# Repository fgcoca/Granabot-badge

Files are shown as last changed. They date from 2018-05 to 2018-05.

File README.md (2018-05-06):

# **Documentación del badge Granabot** 
Se trata de una PCB diseñada en base al logo de Granabot como un kit de soldadura SMD y se basa en un micro controlador ATTiny85 y unos cuantos LEDs con control inteligente tipo WS2812B.

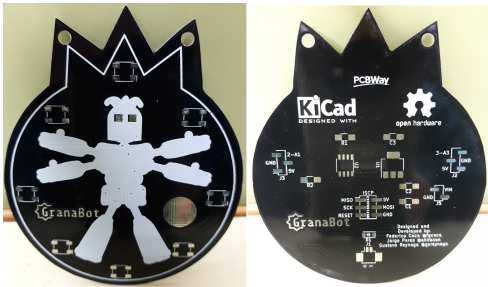
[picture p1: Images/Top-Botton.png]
GrB


 [1]: https://github.com/fgcoca/Granabot-badge/blob/master/Images/Top-Botton.png

# **Contenidos del repositorio**
1. Diseños originales de Gustavo Reynaga de la PCB realizados con [KICad](http://kicad-pcb.org/)

    * [Granabot badge original](https://github.com/fgcoca/Granabot-badge/tree/master/Granabot-Badge-Original)
    * [Imágenes para el diseño](https://github.com/fgcoca/Granabot-badge/tree/master/Granabot-Badge-Original/Design/images)
    * [Diseño para el patrocinio de PCBWay](https://github.com/fgcoca/Granabot-badge/tree/master/Granabot-Badge-Original/Hardware/PCBWay)
    * [Diseño para patrocinio de OSH Park](https://github.com/fgcoca/Granabot-badge/tree/master/Granabot-Badge-Original/Hardware/OSHPark)
2. Debido a dos pequeños errores de encapsulado en el diseño original de Gustavo se hace necesaria la revisión de este para dotar al Attiny85 y al diodo MBRA140 de footprint correctos. La citada revisión y adaptación la Realiza francisco López.

    * [Granabot badge revisado](https://github.com/fgcoca/Granabot-badge/tree/master/Granabot-Badge-revisado)
    * [Diseño para el patrocinio de PCBWay](https://github.com/fgcoca/Granabot-badge/tree/master/Granabot-Badge-revisado/Hardware/PCBWay)
    * [Diseño para patrocinio de OSH Park](https://github.com/fgcoca/Granabot-badge/tree/master/Granabot-Badge-revisado/Hardware/OSHPark)
   
3. Firmware de prueba cargado en los badges que se entregan que sirve para probar el funcionamiento simplemente con alimentarlo. Se trata de un archivo .ino listo para cargarr en el ATTiny85 via ICSP. En el [manual de uso](https://github.com/fgcoca/Granabot-badge/blob/master/Kit/Programacion/Manual.pdf) se explican todos los detalles para trabajar con el badge.
    * [Firmware](https://github.com/fgcoca/Granabot-badge/tree/master/Firmware/badge_granabot)

4. El Kit. Al badge Granabot se le da formato de kit para su entrega estando este formado por la PCB, los componentes necesarios para montarlo, un manual de montaje impreso y una fe de erratas. Todo ello introducido en una cajita adornada con [pegatinas](https://github.com/fgcoca/Granabot-badge/tree/master/Pegatinas-Caja) de Granabot y de los patrocinadores. En las imágenes se ve el aspecto final del kit listo para su entrega de una caja individual y de un conjunto de cajas preparadas para su entrega el día de la celebración del evento [Granabot](https://sites.google.com/site/granabot18/)

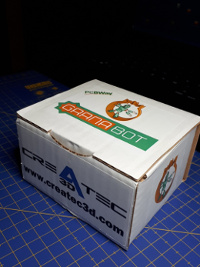
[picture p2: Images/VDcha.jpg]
Vista desde la derecha
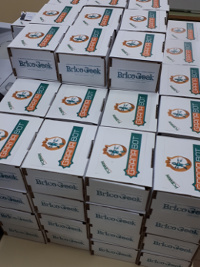
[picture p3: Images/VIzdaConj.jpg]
Conjunto visto desde la izquierda
 

 [10]: https://github.com/fgcoca/Granabot-badge/blob/master/Images/VDcha.jpg
 [11]: https://github.com/fgcoca/Granabot-badge/blob/master/Images/VIzdaConj.jpg

En la imagen vemos a Juan Robles de [Createc](https://createc3d.com/) (uno de nuestros patrocinadores) con el badge recien entregado.

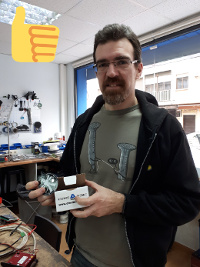
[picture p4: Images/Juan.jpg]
Juan Robles


 [12]: https://github.com/fgcoca/Granabot-badge/blob/master/Images/Juan.jpg

5. Información del kit Granabot

    * [Listas de materiales](https://github.com/fgcoca/Granabot-badge/tree/master/Kit/BOM)
      * [Formato .odt](https://github.com/fgcoca/Granabot-badge/blob/master/Kit/BOM/BOM-con-links-compras.ods)
      * [Formato .pdf](https://github.com/fgcoca/Granabot-badge/blob/master/Kit/BOM/BOM-con-links-compras.pdf)
      * [Formato .png](https://github.com/fgcoca/Granabot-badge/blob/master/Kit/BOM/BOM.png)      
    * [Erratas en la primera edición del kit](https://github.com/fgcoca/Granabot-badge/tree/master/Kit/Erratas)
      * [Formato .odt](https://github.com/fgcoca/Granabot-badge/blob/master/Kit/Erratas/Erratas.odt)
      * [Formato .pdf](https://github.com/fgcoca/Granabot-badge/blob/master/Kit/Erratas/Erratas.pdf)      
    * [Manuales de montaje](https://github.com/fgcoca/Granabot-badge/tree/master/Kit/Montaje)
      * [Formato comprimido .7z](https://github.com/fgcoca/Granabot-badge/blob/master/Kit/Montaje/Manual-montaje.7z)
      * [Formato .pdf](https://github.com/fgcoca/Granabot-badge/blob/master/Kit/Montaje/Manual-montaje.pdf)
      * [Formato .png](https://github.com/fgcoca/Granabot-badge/blob/master/Kit/Montaje/Manual-montaje.png)      
    * [Manuales de configuraciones y uso de librerias para programar el kit](https://github.com/fgcoca/Granabot-badge/tree/master/Kit/Programacion)
      * [Formato .odt](https://github.com/fgcoca/Granabot-badge/blob/master/Kit/Programacion/Manual.odt)
      * [Formato .pdf](https://github.com/fgcoca/Granabot-badge/blob/master/Kit/Programacion/Manual.pdf)
      * [Video de funcionamiento](https://github.com/fgcoca/Granabot-badge/blob/master/Kit/Programacion/video/Test-badge-Granabot.mp4)       
    * [Programando físicamente el kit](https://github.com/fgcoca/Granabot-badge/tree/master/Kit/Programando)
      * [Formato .odt](https://github.com/fgcoca/Granabot-badge/blob/master/Kit/Programando/Programando.odt)
      * [Formato .pdf](https://github.com/fgcoca/Granabot-badge/blob/master/Kit/Programando/Programando.pdf)        
    * [Pinza de sujeción diseñada en 3D](https://github.com/fgcoca/Granabot-badge/tree/master/Kit/Programando/Design)
      * [Diseño en FreeCAD](https://github.com/fgcoca/Granabot-badge/blob/master/Kit/Programando/Design/Pinzas-Centrador.FCStd)
      * [Archivo stl de la pinza](https://github.com/fgcoca/Granabot-badge/blob/master/Kit/Programando/Design/Pinza.stl)  
      * [Archivo stl de la pieza usada para posicionar el chip](https://github.com/fgcoca/Granabot-badge/blob/master/Kit/Programando/Design/Centrador.stl)

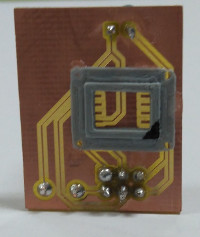
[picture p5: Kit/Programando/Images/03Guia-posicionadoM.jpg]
Guía de posicionado
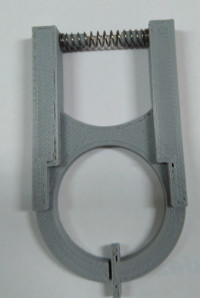
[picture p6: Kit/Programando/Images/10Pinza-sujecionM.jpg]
Pinza de sujeción con el muelle montado
 

 [20]: https://github.com/fgcoca/Granabot-badge/blob/master/Kit/Programando/Images/03Guia-posicionadoM.jpg
 [21]: https://github.com/fgcoca/Granabot-badge/blob/master/Kit/Programando/Images/10Pinza-sujecionM.jpg

# **Enlaces**

[Web de Granabot 2018](https://sites.google.com/site/granabot18/)

# **Autores**
Gustavo Reynaga https://github.com/hulkco @gsreynaga 

Jorge Pérez https://github.com/akirasan @akirasan

José Antonio Vacas https://github.com/javacasm @javacasm

Federico Coca Caba https://github.com/fgcoca @fgcoca

Francisco López Castro @flopcas 

# **Licencia**
License

 [88]: https://github.com/fgcoca/3D-Design_Robots_Other/blob/master/Lapicero/Licencia/licencia.png
[Enlace al texto de la licencia](https://github.com/fgcoca/Granabot-badge/blob/master/LICENSE)

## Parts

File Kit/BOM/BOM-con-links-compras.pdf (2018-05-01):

BOM

## Granabot badge

Quantity | Reference | Value | Description | Supplier
1 | R1 | 1k | 1206 SMD resistor | Link (https://es.aliexpress.com/item/100pcs-lot-SMD-Chip-Resistor-1206-1K-1K-ohm-5-Free-shippng/32382933718.html)
1 | R2 | 1M | 1206 SMD resistor | Link (https://es.aliexpress.com/item/100pcs-lot-SMD-Chip-Resistor-1206-1M-1M-ohm-5-Free-shippng/32385434931.html)
1 | C1 | 4.7uF | 1206 SMD capacitor | Link (https://es.aliexpress.com/item/Free-shipping-1206-SMD-capacitor-4-7UF-25V-475ZM-100PCS/32373664747.html)
1 | C2 | 100nF | 1206 SMD capacitor | Link (https://es.aliexpress.com/item/Free-shipping-1206-SMD-capacitor-100nf-50V-104K-100PCS/32372347475.html)
1 | C3 | 22nF | 1206 SMD capacitor | Link (https://es.aliexpress.com/item/Free-shipping-1206-SMD-capacitor-220nf-50V-224M-100PCS/32373616228.html)
0 | CAP1 | CAPSENSE_CIRCLE | On PCB | None
1 | D1 | MBRA140 | Schottky diode | Link (https://es.aliexpress.com/item/20-unids-MBRA140-MBRA140T3G-DO-214AC/32845565830.html)
1 | D2 | Power | 1206 SMD LED Blue | Link (https://es.aliexpress.com/store/product/Smd-leds-led-smd-blu-ray-1206-languang-bright-double/430356_1288303428.html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)
8 | LED1 to LED8 | WS2812B | Intelligent control LED | Link (https://es.aliexpress.com/item/10-1000pcs-WS2812B-4pins-5050-SMD-Black-White-version-WS2812-Individually-Addressable-Digital-RGB-LED-Chip/32453497583.html)
1 | U1 | LM340MP-5.0/NOPB | Fixed Voltage Regulator | Link (https://es.aliexpress.com/item/LM340MP5-0-LM340-LM340MP-LM340MP-5-0-SOT223/32837352624.html)
1 | U2 | ATTINY85-20SU | Atmel 8-bit AVR Microcontroller | Link (https://es.aliexpress.com/item/FREE-SHIPPING-5piece-ATTINY85-20SU-SOP8-ATTINY85-20-SOP-ATTINY85-SMD-85-20SU/32771436223.html)
1 | J1 | CONN_01X02 | 1.25mm – Connector JST SMD Horizontal | Link (https://es.aliexpress.com/item/100-Set-1-25mm-Pitch-Connector-Mini-JST-Horizontal-Straight-Pin-2-3-4-5-6/32787329436.html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)
2 | J2, J3 | CONN_01X03 | 2.54mm - 1x40 Pins SMD Male | Link (https://es.aliexpress.com/item/200PCS-2-0mm-Pin-Headerr-SMT-1X40P-Single-Row-Single-Plastic-High-Quality-Gold-Plated/32795058148.html)
1 | J4 | CONN_02X03 | 2.54mm - 2x40 Pins SMD Male | Link (https://es.aliexpress.com/item/20pcs-lot-2x40-pins-Double-Row-2-54-mm-Pitch-SMD-Needle-Male-Pin-Header/1691091075.html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)
1 | J5 | CONN_01X02 | 2.54mm - 1x40 Pins SMD Male | Link (https://es.aliexpress.com/item/200PCS-2-0mm-Pin-Headerr-SMT-1X40P-Single-Row-Single-Plastic-High-Quality-Gold-Plated/32795058148.html)

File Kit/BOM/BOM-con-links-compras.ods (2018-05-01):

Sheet: BOM
Granabot badge
Quantity | Reference | Value | Description | Supplier
1 | R1 | 1k | 1206 SMD resistor | Link (https://es.aliexpress.com/item/100pcs-lot-SMD-Chip-Resistor-1206-1K-1K-ohm-5-Free-shippng/32382933718.html)
1 | R2 | 1M | 1206 SMD resistor | Link (https://es.aliexpress.com/item/100pcs-lot-SMD-Chip-Resistor-1206-1M-1M-ohm-5-Free-shippng/32385434931.html)
1 | C1 | 4.7uF | 1206 SMD capacitor | Link (https://es.aliexpress.com/item/Free-shipping-1206-SMD-capacitor-4-7UF-25V-475ZM-100PCS/32373664747.html)
1 | C2 | 100nF | 1206 SMD capacitor | Link (https://es.aliexpress.com/item/Free-shipping-1206-SMD-capacitor-100nf-50V-104K-100PCS/32372347475.html)
1 | C3 | 22nF | 1206 SMD capacitor | Link (https://es.aliexpress.com/item/Free-shipping-1206-SMD-capacitor-220nf-50V-224M-100PCS/32373616228.html)
0 | CAP1 | CAPSENSE_CIRCLE | On PCB | None
1 | D1 | MBRA140 | Schottky diode | Link (https://es.aliexpress.com/item/20-unids-MBRA140-MBRA140T3G-DO-214AC/32845565830.html)
1 | D2 | Power | 1206 SMD LED Blue | Link (https://es.aliexpress.com/store/product/Smd-leds-led-smd-blu-ray-1206-languang-bright-double/430356_1288303428.html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)
8 | LED1 to LED8 | WS2812B | Intelligent control LED | Link (https://es.aliexpress.com/item/10-1000pcs-WS2812B-4pins-5050-SMD-Black-White-version-WS2812-Individually-Addressable-Digital-RGB-LED-Chip/32453497583.html)
1 | U1 | LM340MP-5.0/NOPB | Fixed Voltage Regulator | Link (https://es.aliexpress.com/item/LM340MP5-0-LM340-LM340MP-LM340MP-5-0-SOT223/32837352624.html)
1 | U2 | ATTINY85-20SU | Atmel 8-bit AVR Microcontroller | Link (https://es.aliexpress.com/item/FREE-SHIPPING-5piece-ATTINY85-20SU-SOP8-ATTINY85-20-SOP-ATTINY85-SMD-85-20SU/32771436223.html)
1 | J1 | CONN_01X02 | 1.25mm – Connector JST SMD Horizontal | Link (https://es.aliexpress.com/item/100-Set-1-25mm-Pitch-Connector-Mini-JST-Horizontal-Straight-Pin-2-3-4-5-6/32787329436.html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)
2 | J2, J3 | CONN_01X03 | 2.54mm - 1x40 Pins SMD Male | Link (https://es.aliexpress.com/item/200PCS-2-0mm-Pin-Headerr-SMT-1X40P-Single-Row-Single-Plastic-High-Quality-Gold-Plated/32795058148.html)
1 | J4 | CONN_02X03 | 2.54mm - 2x40 Pins SMD Male | Link (https://es.aliexpress.com/item/20pcs-lot-2x40-pins-Double-Row-2-54-mm-Pitch-SMD-Needle-Male-Pin-Header/1691091075.html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)
1 | J5 | CONN_01X02 | 2.54mm - 1x40 Pins SMD Male | Link (https://es.aliexpress.com/item/200PCS-2-0mm-Pin-Headerr-SMT-1X40P-Single-Row-Single-Plastic-High-Quality-Gold-Plated/32795058148.html)

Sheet: 001
Reference | Value | Footprint | Datasheet | Description | MF_Name | MF_PN | S1_Name | S1_PN
LED1 | WS2812B | OSHwi:WS2812B | http://www.adafruit.com/datasheets/WS2812B.pdf | LED RGB WS2812B W/DVR 4SMD | Adafruit | 1655 | Digikey | 1528-1104-ND
LED2 | WS2812B | OSHwi:WS2812B | http://www.adafruit.com/datasheets/WS2812B.pdf | LED RGB WS2812B W/DVR 4SMD | Adafruit | 1655 | Digikey | 1528-1104-ND
LED3 | WS2812B | OSHwi:WS2812B | http://www.adafruit.com/datasheets/WS2812B.pdf | LED RGB WS2812B W/DVR 4SMD | Adafruit | 1655 | Digikey | 1528-1104-ND
LED4 | WS2812B | OSHwi:WS2812B | http://www.adafruit.com/datasheets/WS2812B.pdf | LED RGB WS2812B W/DVR 4SMD | Adafruit | 1655 | Digikey | 1528-1104-ND
LED5 | WS2812B | OSHwi:WS2812B | http://www.adafruit.com/datasheets/WS2812B.pdf | LED RGB WS2812B W/DVR 4SMD | Adafruit | 1655 | Digikey | 1528-1104-ND
J1 | CONN_01X02 | Connectors_Molex:Molex_PicoBlade_53261-0271_02x1.25mm_Angled
C1 | 4.7uF | Capacitors_SMD:C_1206_HandSoldering
R1 | 1k | Resistors_SMD:R_1206_HandSoldering
D2 | ON | LEDs:LED_1206_HandSoldering
D1 | MBRA140 | OSHwi:D_SOD-123 | http://www.vishay.com/docs/94301/vs-mbra140trpbf.pdf | DIODE SCHOTTKY 40V 1A MBRA140 SMA | Vishay | VS-MBRA140TRPBF | Digikey | VS-MBRA140TRPBFCT-ND
C2 | 0.1uF | Capacitors_SMD:C_1206_HandSoldering
C3 | 22nF | Capacitors_SMD:C_1206_HandSoldering
LED6 | WS2812B | OSHwi:WS2812B | http://www.adafruit.com/datasheets/WS2812B.pdf | LED RGB WS2812B W/DVR 4SMD | Adafruit | 1655 | Digikey | 1528-1104-ND
U2 | ATTINY85-20SU | Housings_SOIC:SOIC-8_3.9x4.9mm_Pitch1.27mm
U1 | LM340MP-5.0/NOPB | TO_SOT_Packages_SMD:SOT-223-3Lead_TabPin2 | http://www.ti.com/lit/ds/symlink/lm340.pdf
J4 | CONN_02X03 | Pin_Headers:Pin_Header_Straight_2x03_Pitch2.54mm_SMD
R2 | 1M Ohms | Resistors_SMD:R_1206_HandSoldering
CAP1 | CAPSENSE_CIRCLE | Granabot:CAPSENSE-CIRCLE2-D10MM
J5 | CONN_01X02 | Pin_Headers:Pin_Header_Straight_1x02_Pitch2.54mm_SMD_Pin1Left
LED7 | WS2812B | OSHwi:WS2812B | http://www.adafruit.com/datasheets/WS2812B.pdf | LED RGB WS2812B W/DVR 4SMD | Adafruit | 1655 | Digikey | 1528-1104-ND
LED8 | WS2812B | OSHwi:WS2812B | http://www.adafruit.com/datasheets/WS2812B.pdf | LED RGB WS2812B W/DVR 4SMD | Adafruit | 1655 | Digikey | 1528-1104-ND
J2 | CONN_01X03 | Pin_Headers:Pin_Header_Straight_1x03_Pitch2.54mm_SMD_Pin1Left
J3 | CONN_01X03 | Pin_Headers:Pin_Header_Straight_1x03_Pitch2.54mm_SMD_Pin1Right

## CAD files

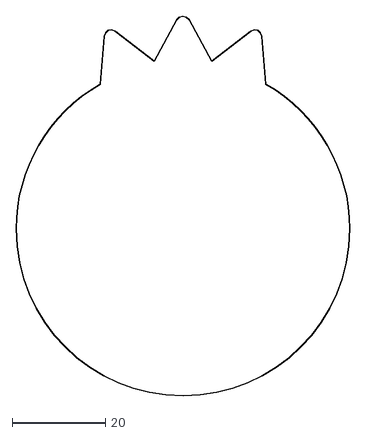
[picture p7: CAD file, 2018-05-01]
Granabot-Badge-Original/Design/images/DXF/contorno.dxf
71.5 x 81.3

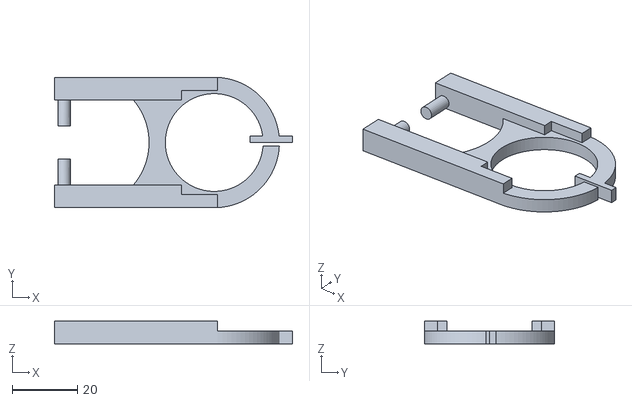
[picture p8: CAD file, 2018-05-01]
Kit/Programando/Design/Pinza.stl
73.0 x 40.0 x 7.00

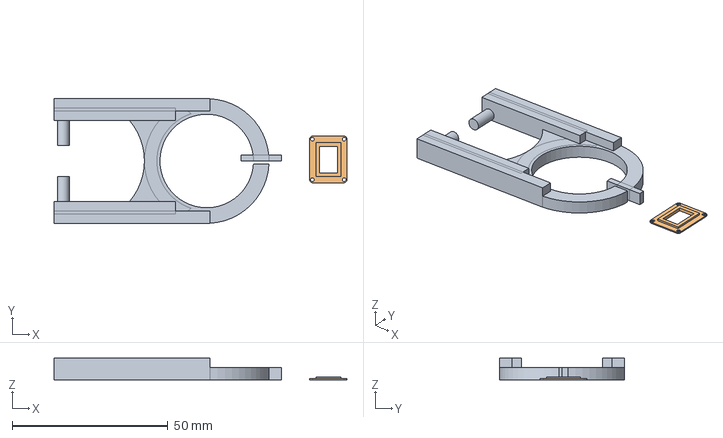
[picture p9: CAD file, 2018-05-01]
Kit/Programando/Design/Pinzas-Centrador.FCStd
94.0 x 40.0 x 7.00 mm
Clone of Pinza-final
Clone of Centrador

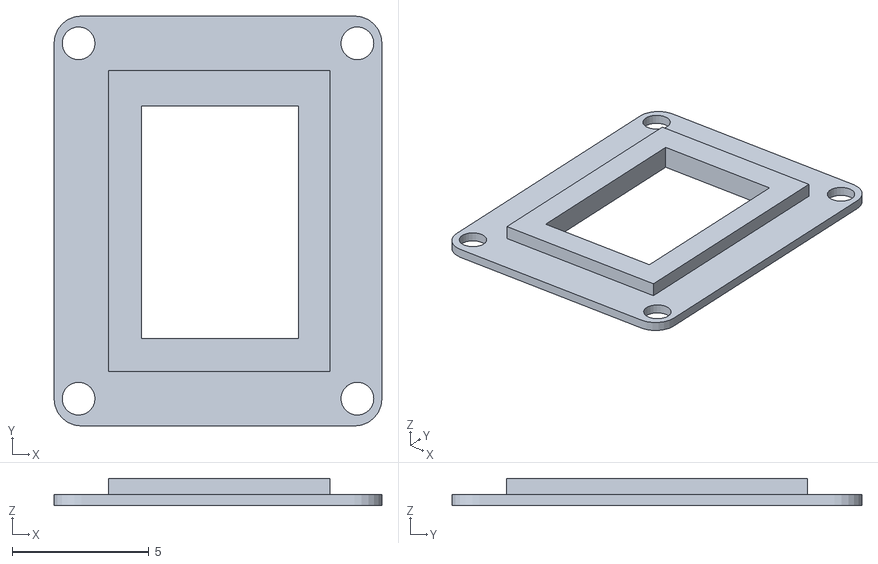
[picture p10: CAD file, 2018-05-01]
Kit/Programando/Design/Centrador.stl
12.0 x 15.0 x 1.00

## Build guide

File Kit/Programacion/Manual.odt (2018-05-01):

Granabot Badge

Guía de Programación

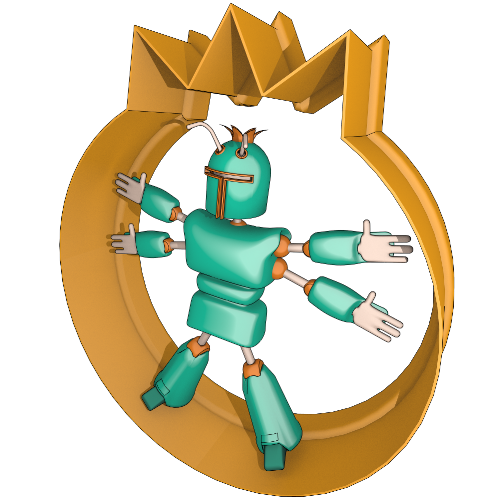
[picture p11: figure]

# Introducción

Los materiales que necesitaremos, además del propio badge, son una placa Arduino UNO o similar, que hará las funciones de programador, un cable ICSP, que deberemos confeccionar nosotros mismos, y un cable USB, para conectar la placa Arduino al ordenador. En cuanto a los programas y librerías necesarias, usaremos el propio IDE de Arduino, descargable desde www.arduino.cc, y las librerías CapacitiveSensor (https://github.com/PaulStoffregen/CapacitiveSensor), originalmente escrita por Paul Bagder y mantenida actualmente por Paul Sttofregen, y Adafruit_NeoPixel (https://github.com/adafruit/Adafruit_NeoPixel), de Adafruit. Ambas librerías las podemos instalar usando el gestor de librerías incluido en el IDE de Arduino.

# El cable ICSP

Nos va a permitir programar el ATTiny85 del badge a través del conector ICSP (In Circuit Serial Programming, programación serie en circuito). Consiste en un mazo o manguera de 6 cables. En uno de los extremos tiene un conector de 2x3 pines hembra, en nuestro caso construido a partir de dos tiras de 1x3 pines hembra unidas entre sí. En el otro extremo se encuentra otro conector similar al anterior pero en el que solo se usan 5 de los 6 pines. Al cable que en este extremo queda libre se le añade un pin macho.

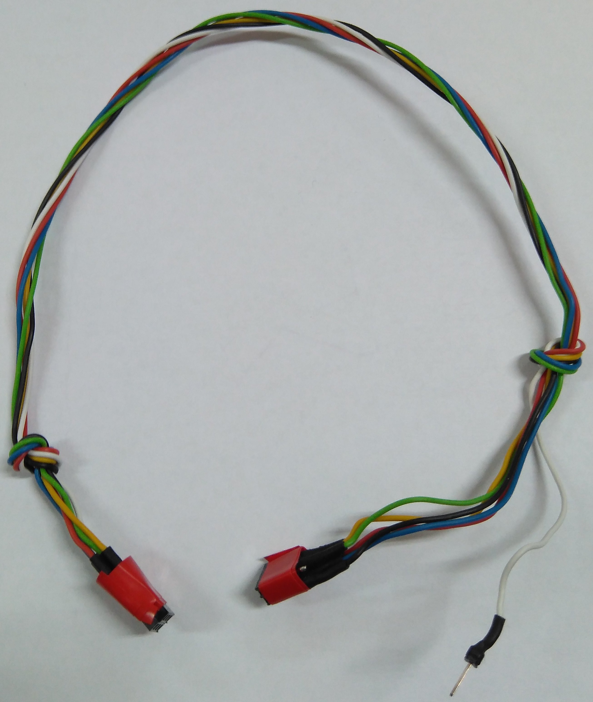
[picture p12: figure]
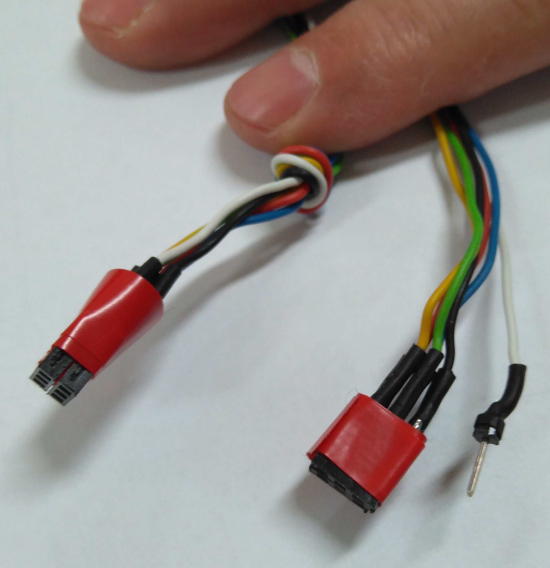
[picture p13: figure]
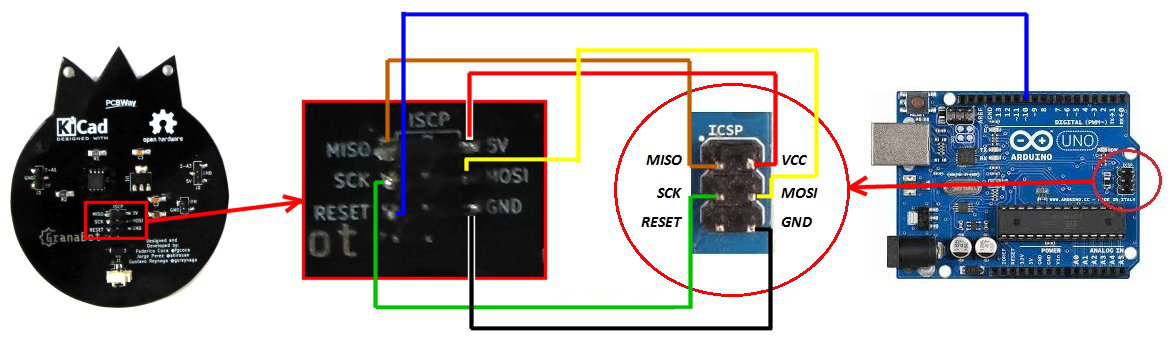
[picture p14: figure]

El conexionado entre el Badge y Arduino es el siguiente:

Una imagen real de este conexionado dará una mejor idea del mismo:

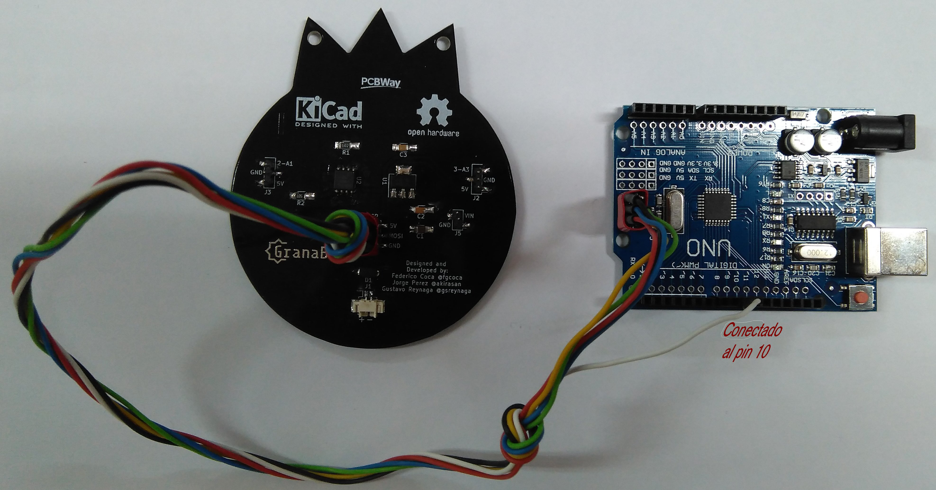
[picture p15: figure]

# Preparación de Arduino para usarlo como programador

Para poder programar el badge usando un Arduino (UNO en este caso) deberemos realizar un proceso que empieza por conectar el Arduino al ordenador y arrancar el IDE. Los ajustes de dicho IDE deberán ser los habituales, es decir, la placa seleccionada debe ser Arduino UNO y el puerto el adecuado:

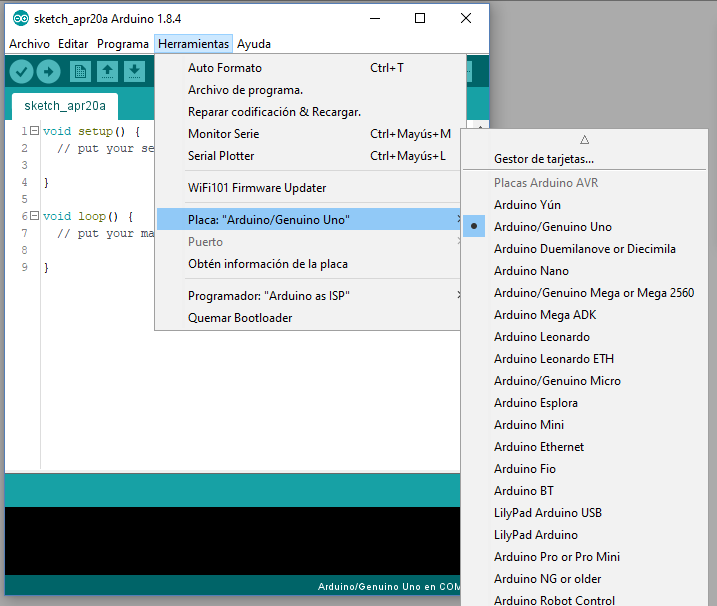
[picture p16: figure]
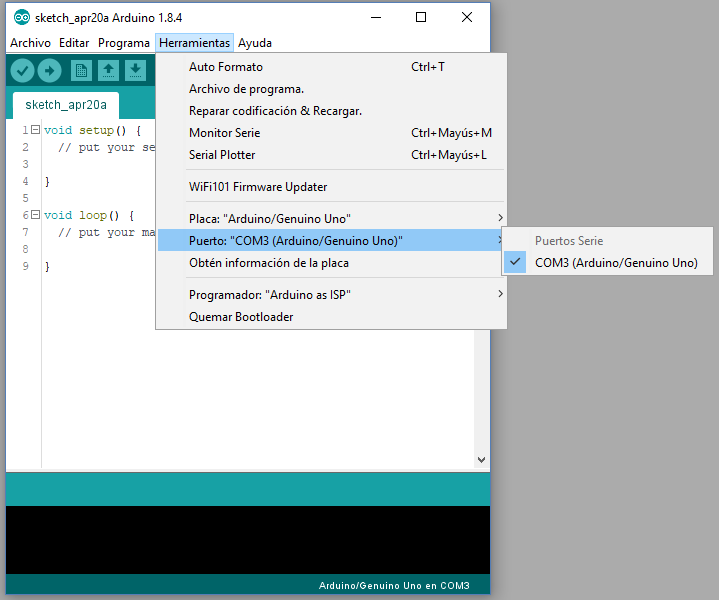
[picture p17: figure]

Seguidamente abriremos el ejemplo ArduinoISP:

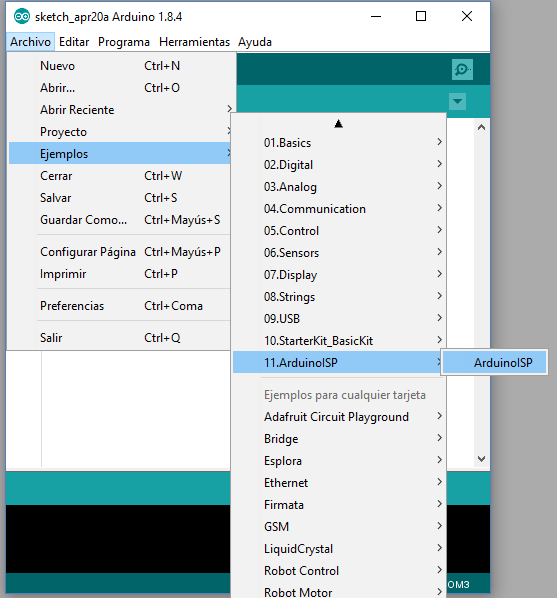
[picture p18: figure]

Cargaremos este sketch en Arduino UNO sin modificar nada del mismo. Tras esto nuestro Arduino se habrá convertido en un programador ICSP.

# Preparar el IDE para trabajar con el ATTiny85

El ATTiny85 no forma parte de las “placas” que el IDE de Arduino es capaz de programar. Sin embargo, gracias a David A. Mellis que ha desarrollado los cores necesarios, podemos hacer que el IDE reconozca nuestro ATTiny85 para poder programarlo como si de una placa Arduino más se tratara. Para lograr esto deberemos empezar por abrir el gestor de tarjetas:

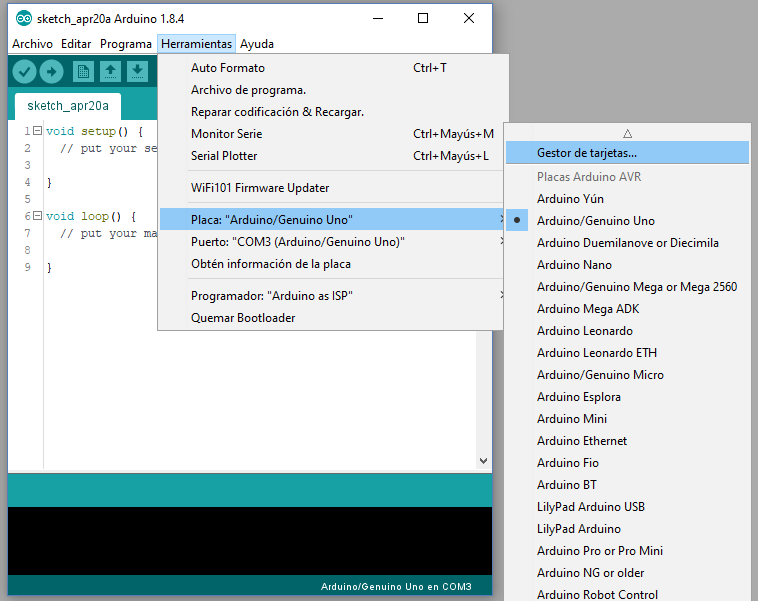
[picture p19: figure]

En dicho gestor buscaremos la tarjeta attiny:

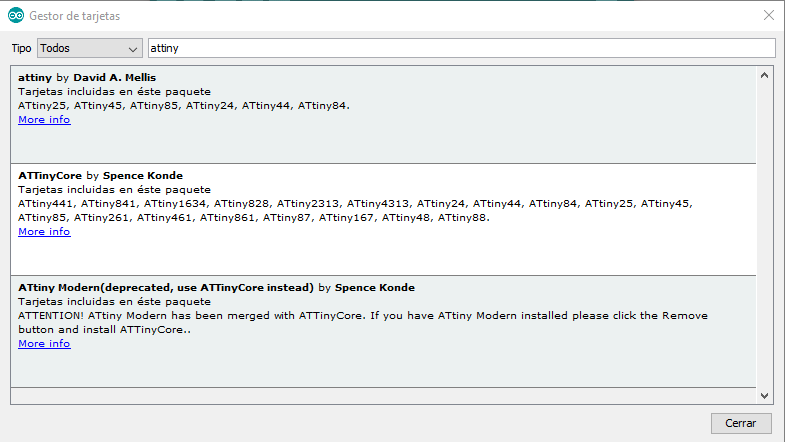
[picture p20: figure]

Seleccionaremos la tarjeta attiny by David A. Mellis y la instalaremos. A continuación seleccionaremos la tarjeta ATTiny85:

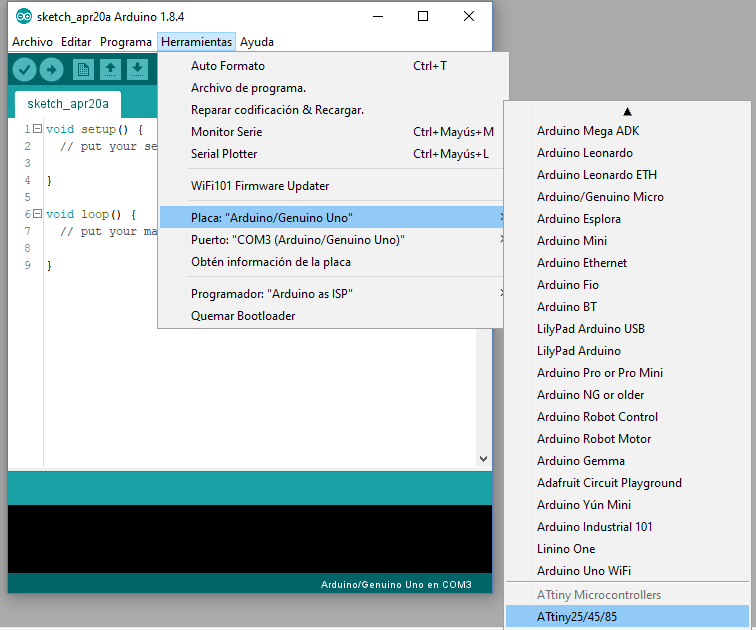
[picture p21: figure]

Tras hacer esto debemos seleccionar el ATTiny85:

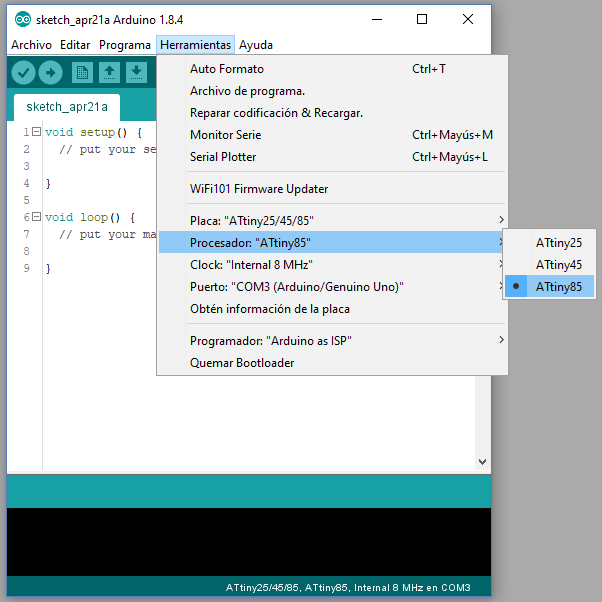
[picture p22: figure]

Por último deberemos indicarle al IDE que queremos usar el Ardunio UNO como programador del badge:

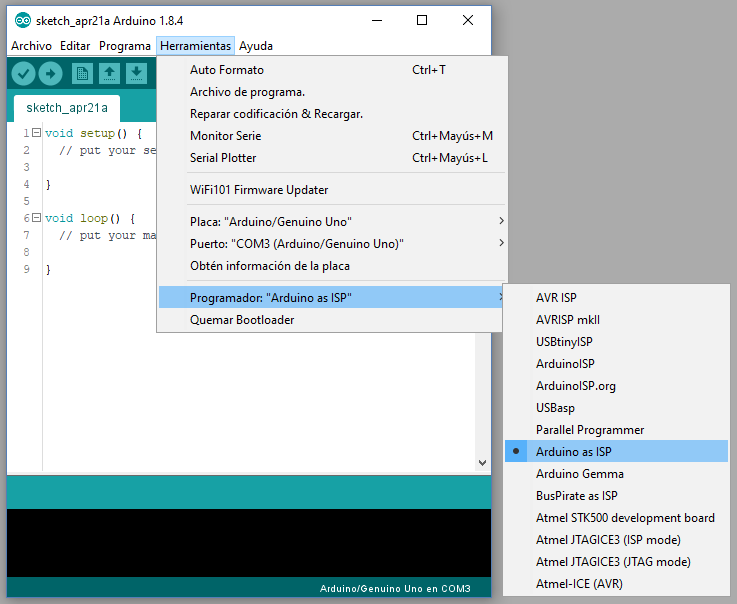
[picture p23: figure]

# Cambiar los fuses del ATTiny85

El ATTiny85 viene de fábrica con sus fuses programados de tal forma que está configurado para trabajar con el reloj interno a 1MHz. Con esta configuración por defecto el badge no puede usar la librería Adafruit Neopixel. Es por esto que en GranaBot suministramos el ATTiny85 del badge configurado para que use el reloj interno a 8MHz. Si se tiene necesidad de cambiar esto sólo hay que empezar por seleccionar la opción adecuada:

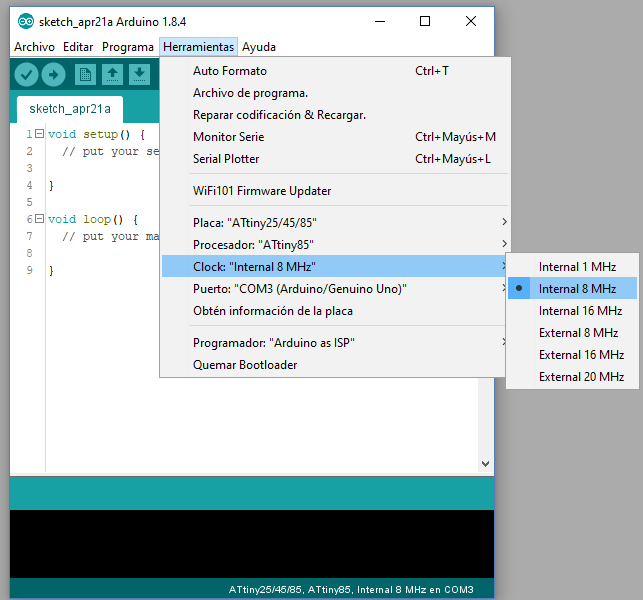
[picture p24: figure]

Y proceder a programar los fuses:

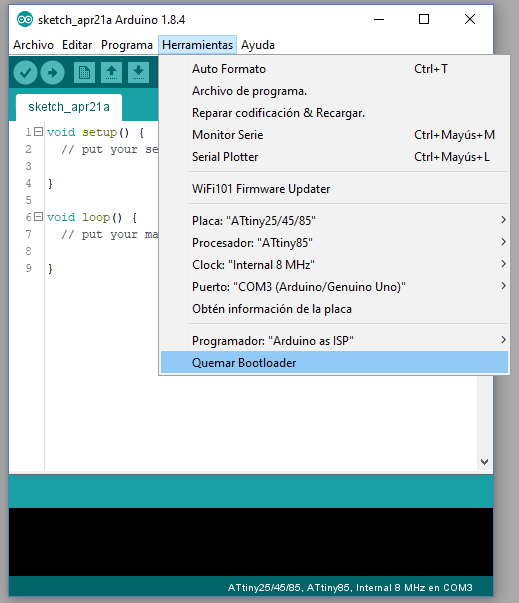
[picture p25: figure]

# Uso básico de la librería CapacitiveSensor

Es la librería que podemos usar para leer el sensor capacitivo incluido en el badge. Esta librería trabaja con un objeto de tipo CapacitiveSensor. Dicho objeto viene a ser una “digitalización” del sensor físico existente en el badge. Es decir, es una especie de representación digital abstracta, existente en el interior de Arduino, y que se corresponde con el sensor físico, real, disponible en la placa (Muy al estilo de Tron, una película estadounidense de 1982, del género ciencia ficción escrita y dirigida por Steven Lisberger).

El primer paso para trabajar con esta librería es incluirla como fichero de cabecera con la directiva #include :

#include <CapacitiveSensor.h>

Hecho esto deberemos continuar por crear una instancia de la clase CapacitiveSensor. Esta instancia es el objeto que representa al sensor físico del badge, tal como se ha comentado más arriba:

CapacitiveSensor mi_sensor = CapacitiveSensor (pin 1, pin2);

El objeto creado se llama en este caso mi_sensor y, debido al hardware del badge, el pin 1 deberá ser el pin PB0 y pin 2 el pin PB1.

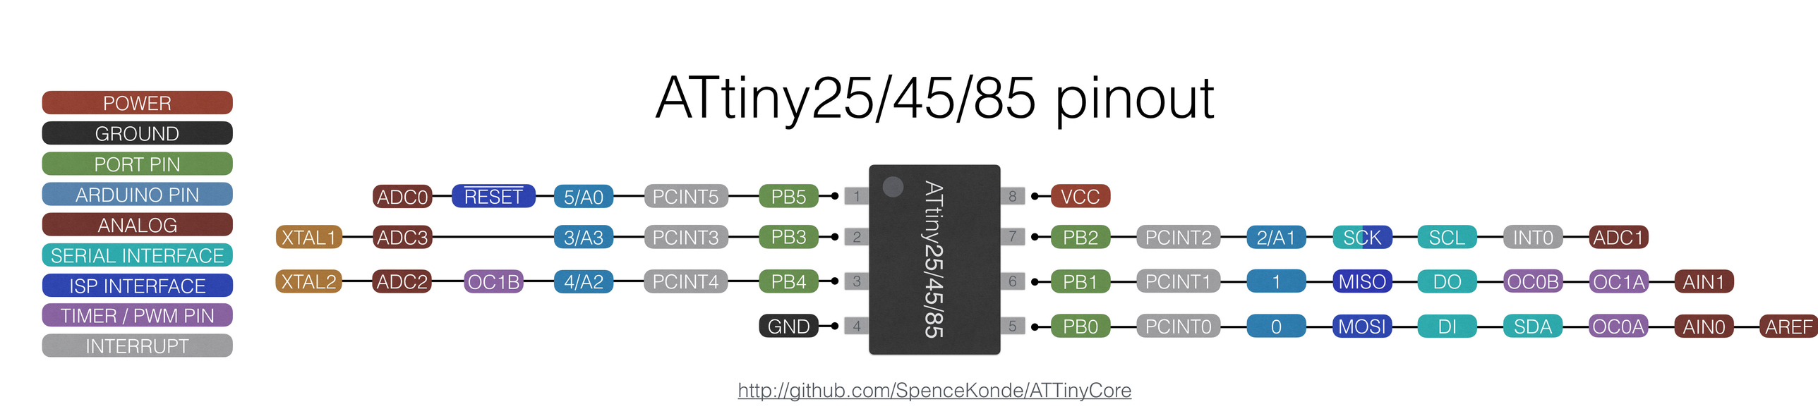
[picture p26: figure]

Para la lectura del sensor usaremos la función CapacitiveSensor(muestras). Esta función devuelve el valor de la capacidad que tiene el sensor (devolverá un valor bajo si no se está tocando el sensor) en unidades arbitrarias. El parámetro muestras específicamente cuantas muestras sucesivas se toman para determinar la capacidad del sensor durante la medida. El resultado devuelto será una media de todos los valores muestreados. Por tanto, para realizar una medida de la capacidad del sensor procederemos de la siguiente forma:

long medida_sensor = mi_sensor.CapacitiveSensor (10);

De esta forma en la variable medida_sensor se almacena el valor medio resultado de 10 medidas sucesivas de la capacidad del sensor. Si se toca el sensor este valor será más o menos elevado. Si no se toca será un valor bajo.

# Uso básico de la librería Adafruit_NeoPixel

Usaremos esta librería para el control de los LEDs RGB incluidos en el badge. Esta librería solo funciona con frecuencias de reloj del micro-controlador iguales o mayores de 8MHz. Como siempre, para poder usar las funciones disponibles en la librería deberemos empezar por incluir la misma en nuestro sketch:

#include <Adafruit_NeoPixel.h>

También, como en el caso descrito anteriormente, será necesario instanciar la clase Adafruit_NeoPixel para crear el objeto que representa a la “tira de LEDs” incluida en el badge:

Adafruit_NeoPixel mis_LEDs = Adafruit_NeoPixel (8, PB4, NEO_GRB + NEO_KHZ800);

El 8 se debe a que nuestro badge tiene 8 LEDs RGB. PB4 es el pin del ATTiny encargado de controlar los LEDs RGB. El resto… bueno, es lo que hay que poner en el caso que nos ocupa (ver https://learn.adafruit.com/adafruit-neopixel-uberguide/arduino-library-use o sketch de ejemplo strandtest.ino incluido al instalar la librería para más detalles).

Una vez creada nuestra “imagen virtual” de los LEDs del badge en el interior del ATTiny85 ya podemos empezar a controlarlos mediante las funciones que nos proporciona la librería. Habrá que empezar por ajustar el brillo máximo de los LEDs e inicializar el objeto creado. Normalmente esto se hace dentro del setup del sketch:

mis_LEDs.setBrightness(brillo);

mis_LEDs.begin();

El valor dado al brillo máximo tiene que ser de tipo byte, o sea, entre 0 y 255.

Para controlar el color de cada uno de los LEDs del badge usaremos la siguiente función:

mis_LEDs.setPixelColor(n, rojo, verde, azul);

Esta función ajusta el color del LED número n (en nuestro caso n es un número entero entre 0 y 7). Los colores, rojo, verde y azul, son de tipo byte. El efecto de esta función no se refleja inmediatamente en los LEDs. Para que ello ocurra deberemos mandar la nueva configuración de color de los LEDs a los mismos empleando la función siguiente:

mis_LEDs.show();

# Test de funcionamiento

En los enlaces siguientes podemos ver el video de funcionamiento del badge con el firmware grabado por defecto en el mismo.

Enlace al video en Youtube –> https://youtu.be/pwC2fTl5S1I

Enlace al video en Github –> https://github.com/fgcoca/Granabot-badge/blob/master/Kit/Programacion/video/Test-badge-Granabot.mp4

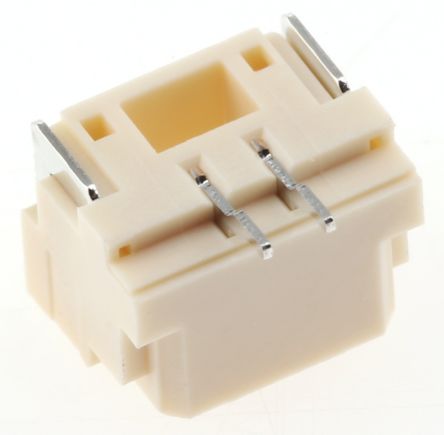
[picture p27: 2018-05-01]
Kit/Montaje/Images/JST-M-2-I.jpg

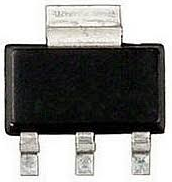
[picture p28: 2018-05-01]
Kit/Montaje/Images/LM340MP.png

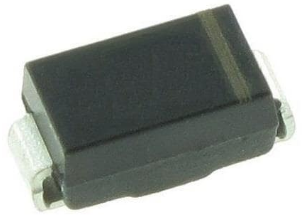
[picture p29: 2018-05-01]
Kit/Montaje/Images/MBRA140.png

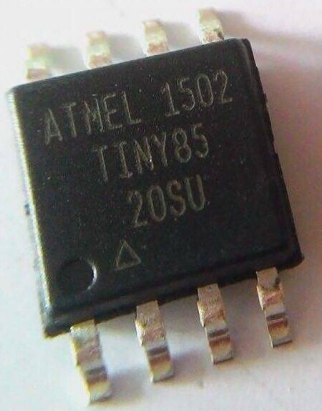
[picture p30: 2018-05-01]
Kit/Montaje/Images/ATTINY85.png

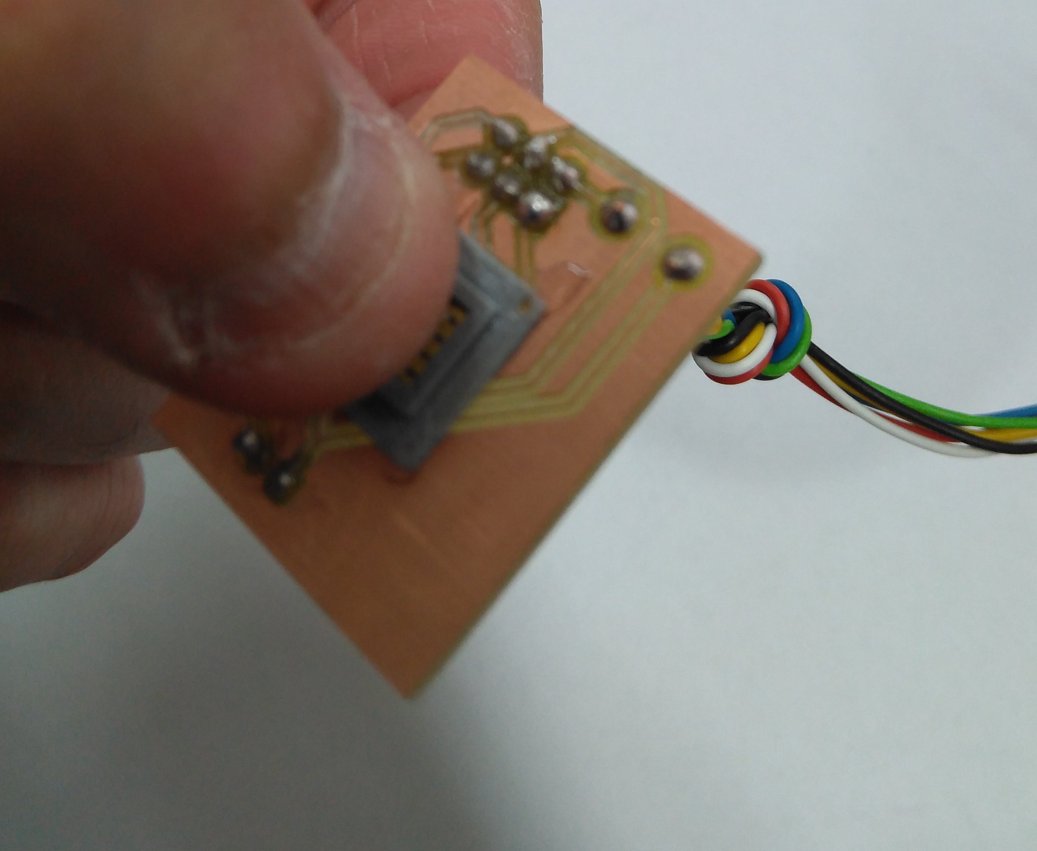
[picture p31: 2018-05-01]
Kit/Programando/Images/09Sujecion-manual.jpg

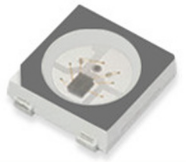
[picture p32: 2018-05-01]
Kit/Montaje/Images/WS2812B-I.png

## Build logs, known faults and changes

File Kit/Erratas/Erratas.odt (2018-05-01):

Errores que en todo los casos suponen un reto de soldadura | | Errores que en todo los casos suponen un reto de soldadura
D1 MBRA140 | Se diseña con encapsulado SOD-123 Encapsulado real DO-214AC (SMA) | D1 MBRA140 | Se diseña con encapsulado SOD-123 Encapsulado real DO-214AC (SMA)
U2 ATTINY85 | Se diseña con encapsulado SOIC-8 Encapsulado real EIAJ (8S2) | U2 ATTINY85 | Se diseña con encapsulado SOIC-8 Encapsulado real EIAJ (8S2)
J2, J3 y J5 CONN_01X03 | Se diseña con pitch 2,54mm Se compra con pitch 2 mm | J2, J3 y J5 CONN_01X03 | Se diseña con pitch 2,54mm Se compra con pitch 2 mm
Errores que en todo los casos suponen un reto de soldadura | | Errores que en todo los casos suponen un reto de soldadura
D1 MBRA140 | Se diseña con encapsulado SOD-123 Encapsulado real DO-214AC (SMA) | D1 MBRA140 | Se diseña con encapsulado SOD-123 Encapsulado real DO-214AC (SMA)
U2 ATTINY85 | Se diseña con encapsulado SOIC-8 Encapsulado real EIAJ (8S2) | U2 ATTINY85 | Se diseña con encapsulado SOIC-8 Encapsulado real EIAJ (8S2)
J2, J3 y J5 CONN_01X03 | Se diseña con pitch 2,54mm Se compra con pitch 2 mm | J2, J3 y J5 CONN_01X03 | Se diseña con pitch 2,54mm Se compra con pitch 2 mm
Errores que en todo los casos suponen un reto de soldadura | | Errores que en todo los casos suponen un reto de soldadura
D1 MBRA140 | Se diseña con encapsulado SOD-123 Encapsulado real DO-214AC (SMA) | D1 MBRA140 | Se diseña con encapsulado SOD-123 Encapsulado real DO-214AC (SMA)
U2 ATTINY85 | Se diseña con encapsulado SOIC-8 Encapsulado real EIAJ (8S2) | U2 ATTINY85 | Se diseña con encapsulado SOIC-8 Encapsulado real EIAJ (8S2)
J2, J3 y J5 CONN_01X03 | Se diseña con pitch 2,54mm Se compra con pitch 2 mm | J2, J3 y J5 CONN_01X03 | Se diseña con pitch 2,54mm Se compra con pitch 2 mm
Errores que en todo los casos suponen un reto de soldadura | | Errores que en todo los casos suponen un reto de soldadura
D1 MBRA140 | Se diseña con encapsulado SOD-123 Encapsulado real DO-214AC (SMA) | D1 MBRA140 | Se diseña con encapsulado SOD-123 Encapsulado real DO-214AC (SMA)
U2 ATTINY85 | Se diseña con encapsulado SOIC-8 Encapsulado real EIAJ (8S2) | U2 ATTINY85 | Se diseña con encapsulado SOIC-8 Encapsulado real EIAJ (8S2)
J2, J3 y J5 CONN_01X03 | Se diseña con pitch 2,54mm Se compra con pitch 2 mm | J2, J3 y J5 CONN_01X03 | Se diseña con pitch 2,54mm Se compra con pitch 2 mm
Errores que en todo los casos suponen un reto de soldadura | | Errores que en todo los casos suponen un reto de soldadura
D1 MBRA140 | Se diseña con encapsulado SOD-123 Encapsulado real DO-214AC (SMA) | D1 MBRA140 | Se diseña con encapsulado SOD-123 Encapsulado real DO-214AC (SMA)
U2 ATTINY85 | Se diseña con encapsulado SOIC-8 Encapsulado real EIAJ (8S2) | U2 ATTINY85 | Se diseña con encapsulado SOIC-8 Encapsulado real EIAJ (8S2)
J2, J3 y J5 CONN_01X03 | Se diseña con pitch 2,54mm Se compra con pitch 2 mm | J2, J3 y J5 CONN_01X03 | Se diseña con pitch 2,54mm Se compra con pitch 2 mm
Errores que en todo los casos suponen un reto de soldadura | | Errores que en todo los casos suponen un reto de soldadura
D1 MBRA140 | Se diseña con encapsulado SOD-123 Encapsulado real DO-214AC (SMA) | D1 MBRA140 | Se diseña con encapsulado SOD-123 Encapsulado real DO-214AC (SMA)
U2 ATTINY85 | Se diseña con encapsulado SOIC-8 Encapsulado real EIAJ (8S2) | U2 ATTINY85 | Se diseña con encapsulado SOIC-8 Encapsulado real EIAJ (8S2)
J2, J3 y J5 CONN_01X03 | Se diseña con pitch 2,54mm Se compra con pitch 2 mm | J2, J3 y J5 CONN_01X03 | Se diseña con pitch 2,54mm Se compra con pitch 2 mm
Errores que en todo los casos suponen un reto de soldadura | | Errores que en todo los casos suponen un reto de soldadura
D1 MBRA140 | Se diseña con encapsulado SOD-123 Encapsulado real DO-214AC (SMA) | D1 MBRA140 | Se diseña con encapsulado SOD-123 Encapsulado real DO-214AC (SMA)
U2 ATTINY85 | Se diseña con encapsulado SOIC-8 Encapsulado real EIAJ (8S2) | U2 ATTINY85 | Se diseña con encapsulado SOIC-8 Encapsulado real EIAJ (8S2)
J2, J3 y J5 CONN_01X03 | Se diseña con pitch 2,54mm Se compra con pitch 2 mm | J2, J3 y J5 CONN_01X03 | Se diseña con pitch 2,54mm Se compra con pitch 2 mm

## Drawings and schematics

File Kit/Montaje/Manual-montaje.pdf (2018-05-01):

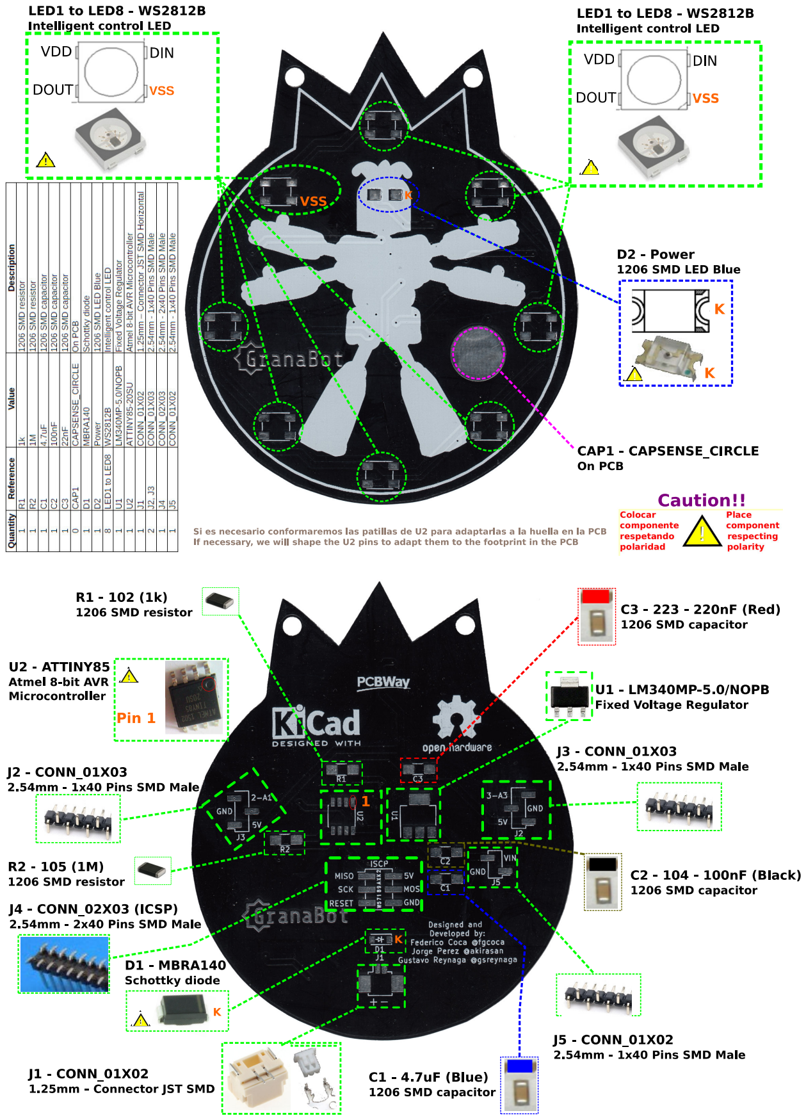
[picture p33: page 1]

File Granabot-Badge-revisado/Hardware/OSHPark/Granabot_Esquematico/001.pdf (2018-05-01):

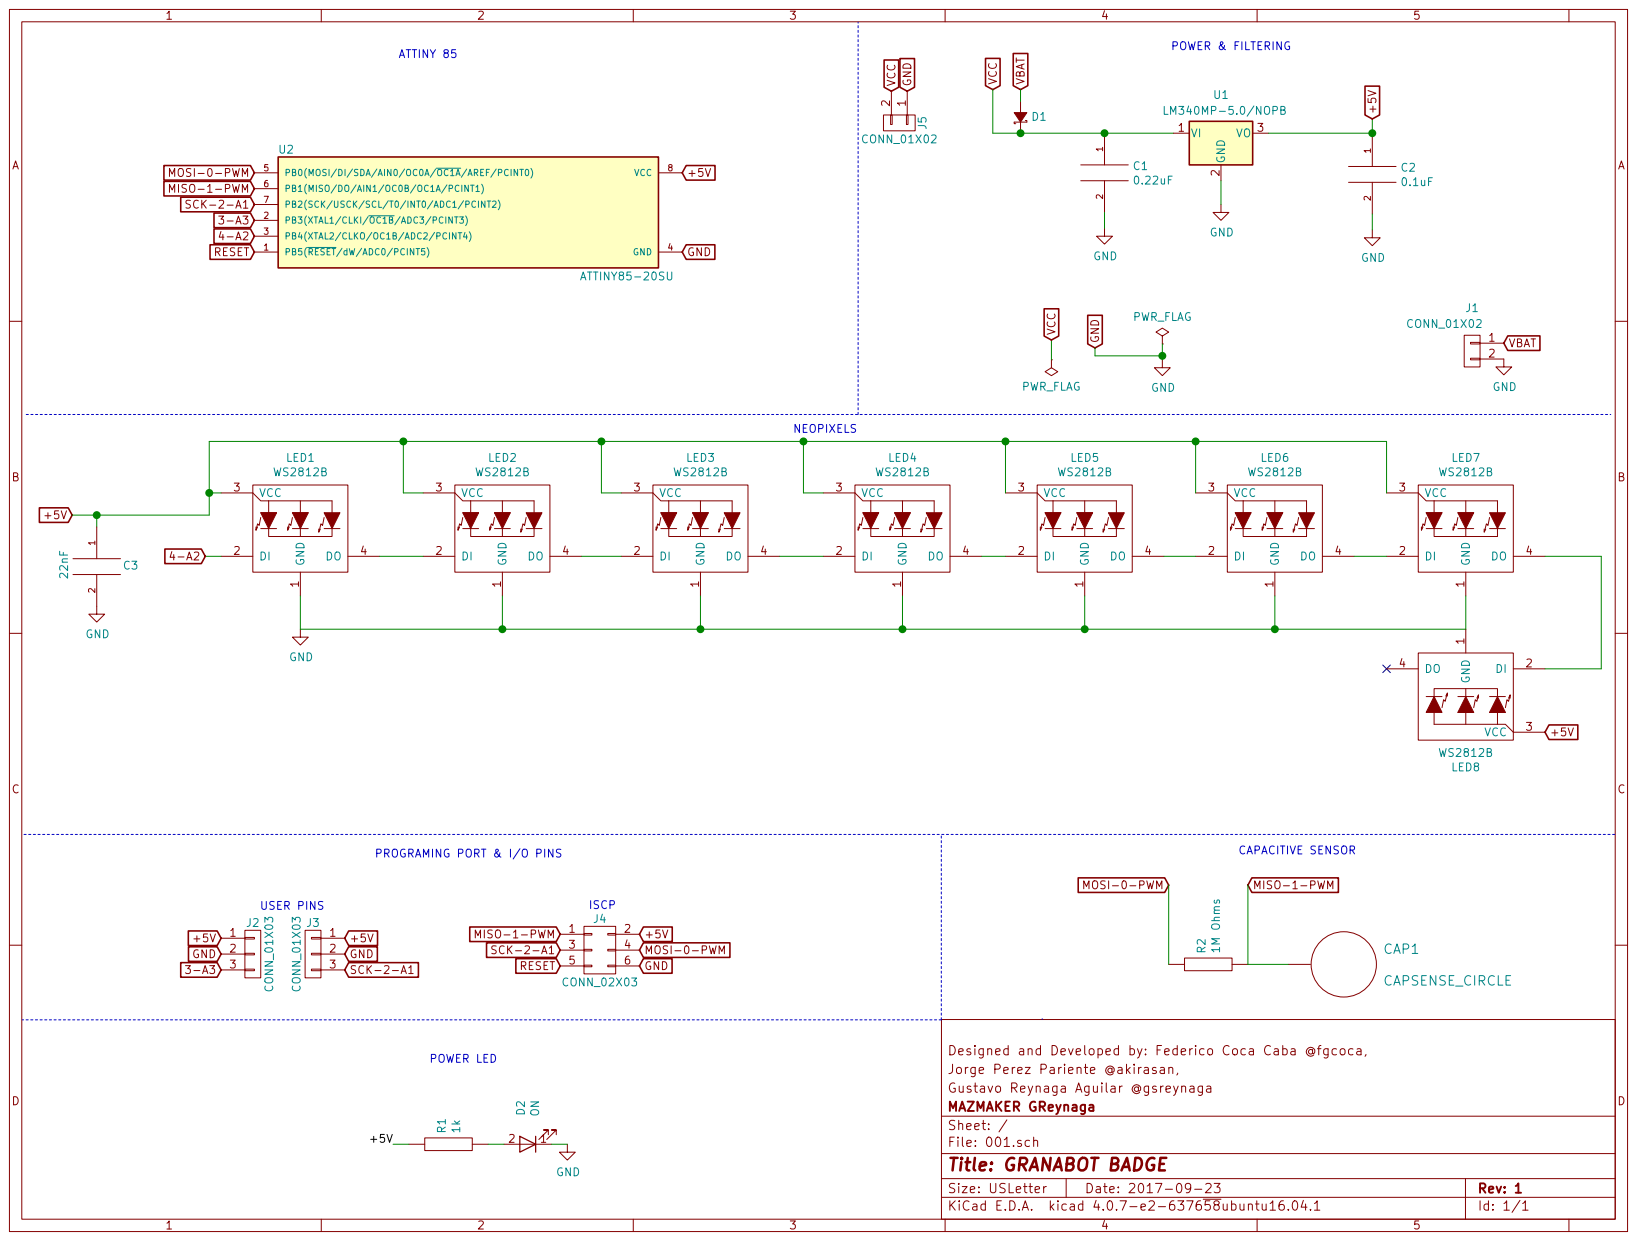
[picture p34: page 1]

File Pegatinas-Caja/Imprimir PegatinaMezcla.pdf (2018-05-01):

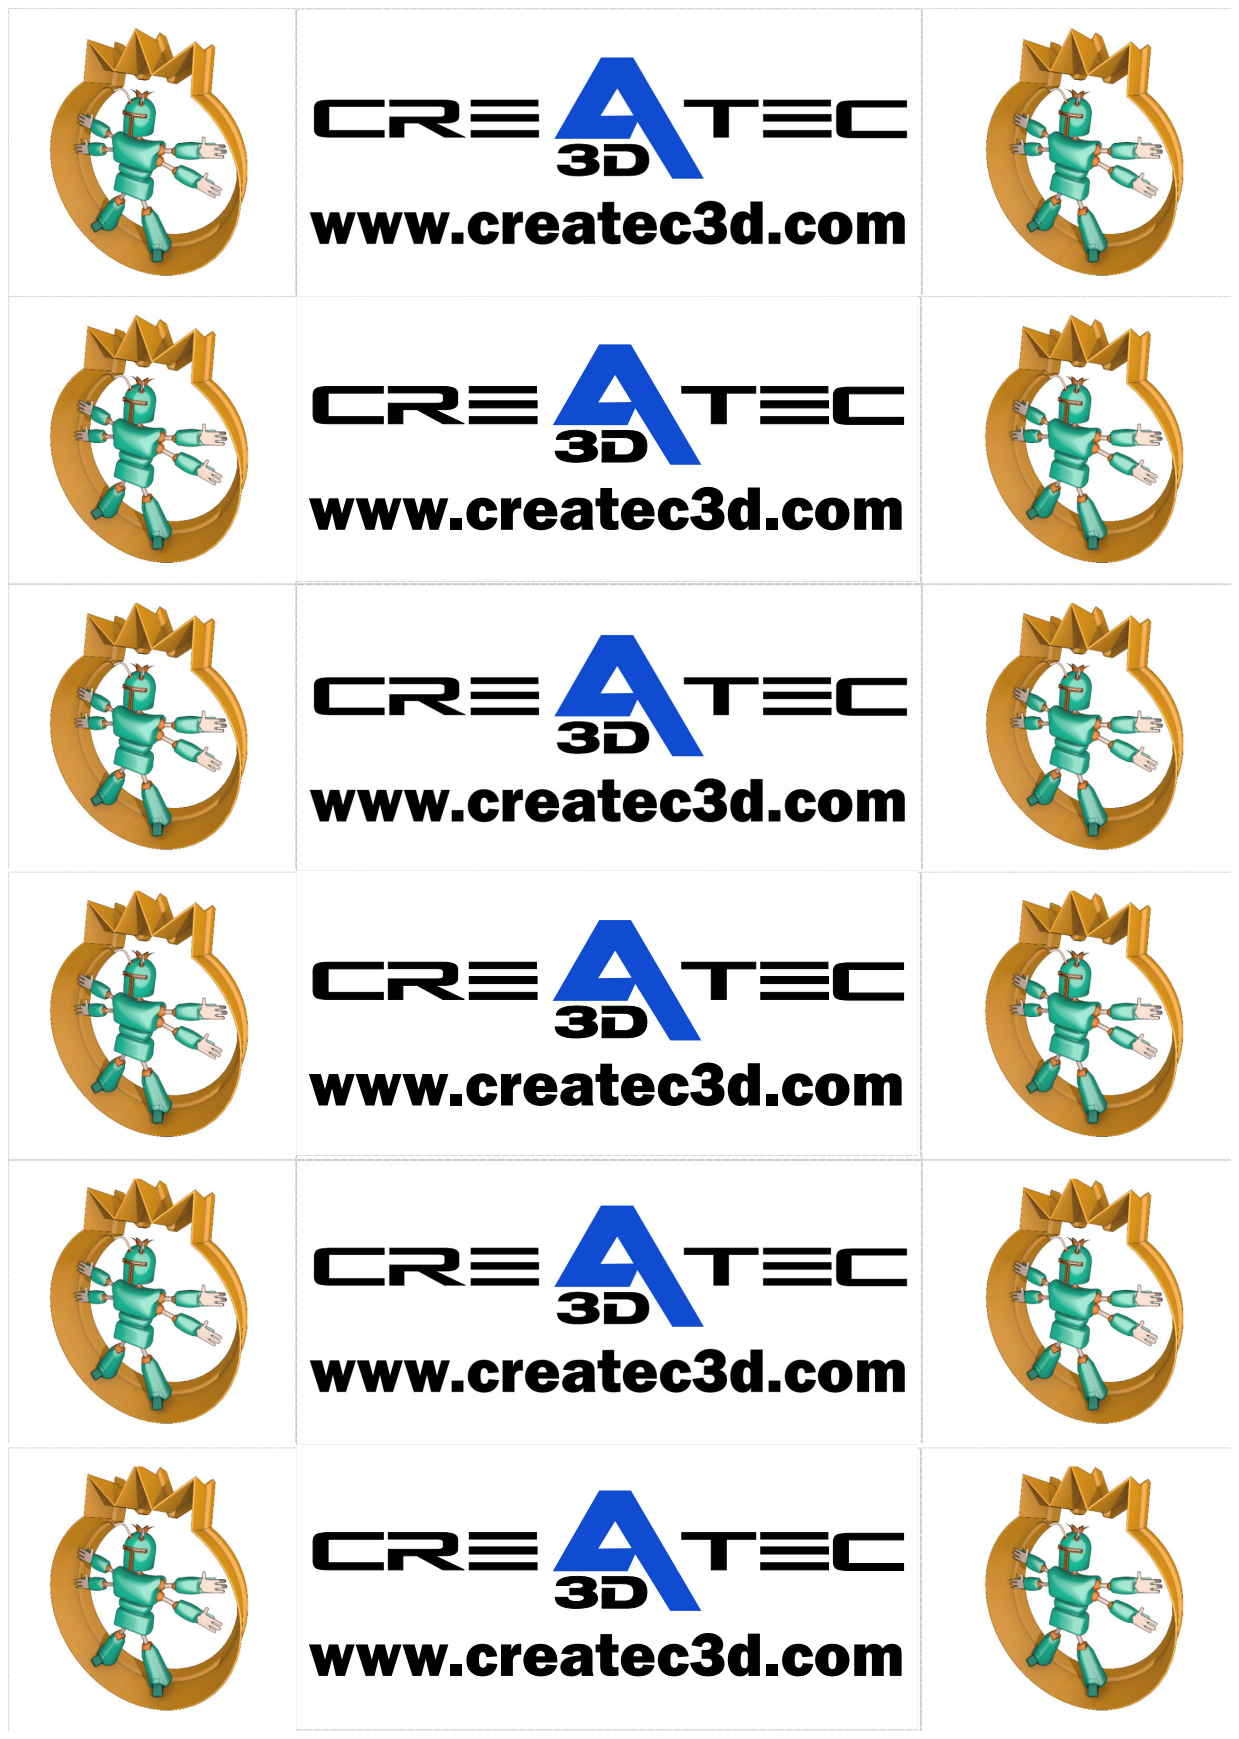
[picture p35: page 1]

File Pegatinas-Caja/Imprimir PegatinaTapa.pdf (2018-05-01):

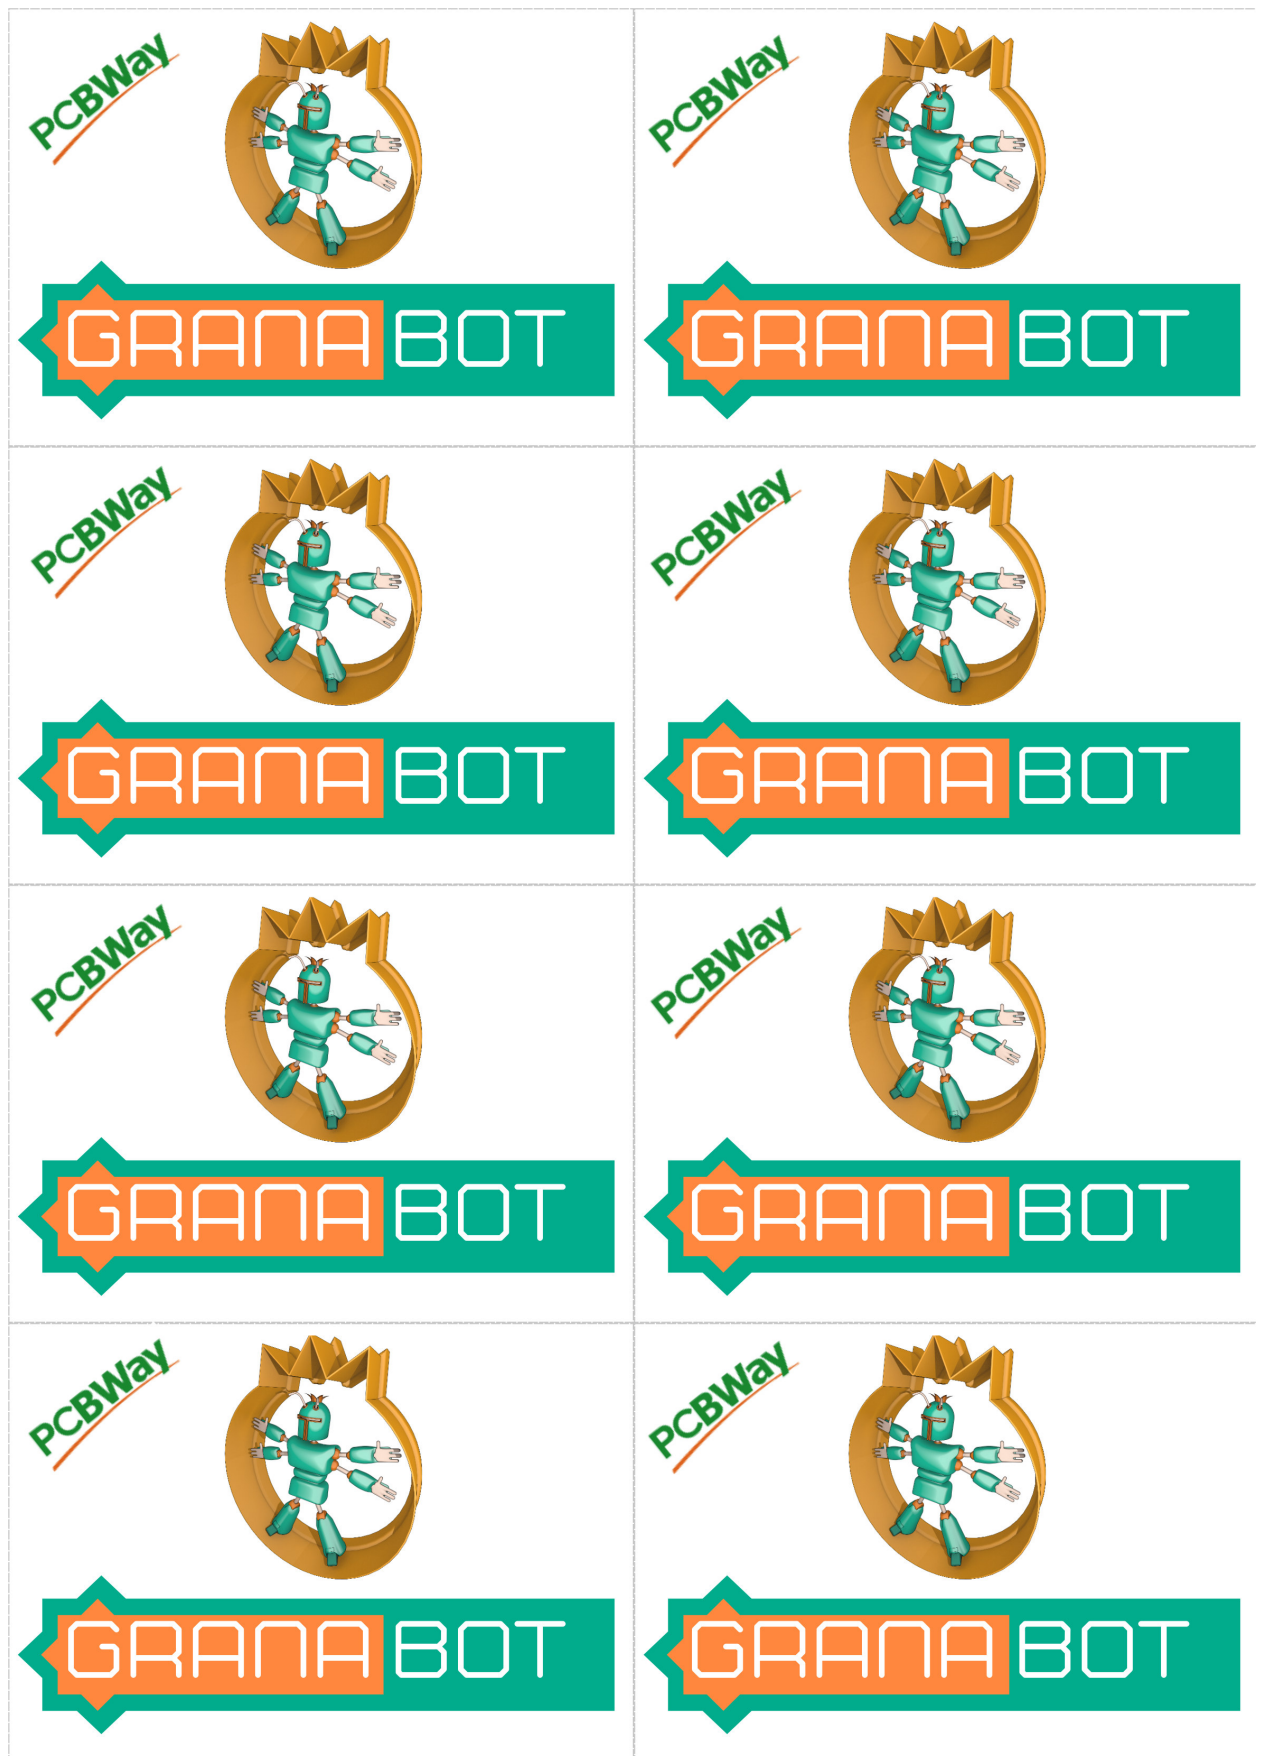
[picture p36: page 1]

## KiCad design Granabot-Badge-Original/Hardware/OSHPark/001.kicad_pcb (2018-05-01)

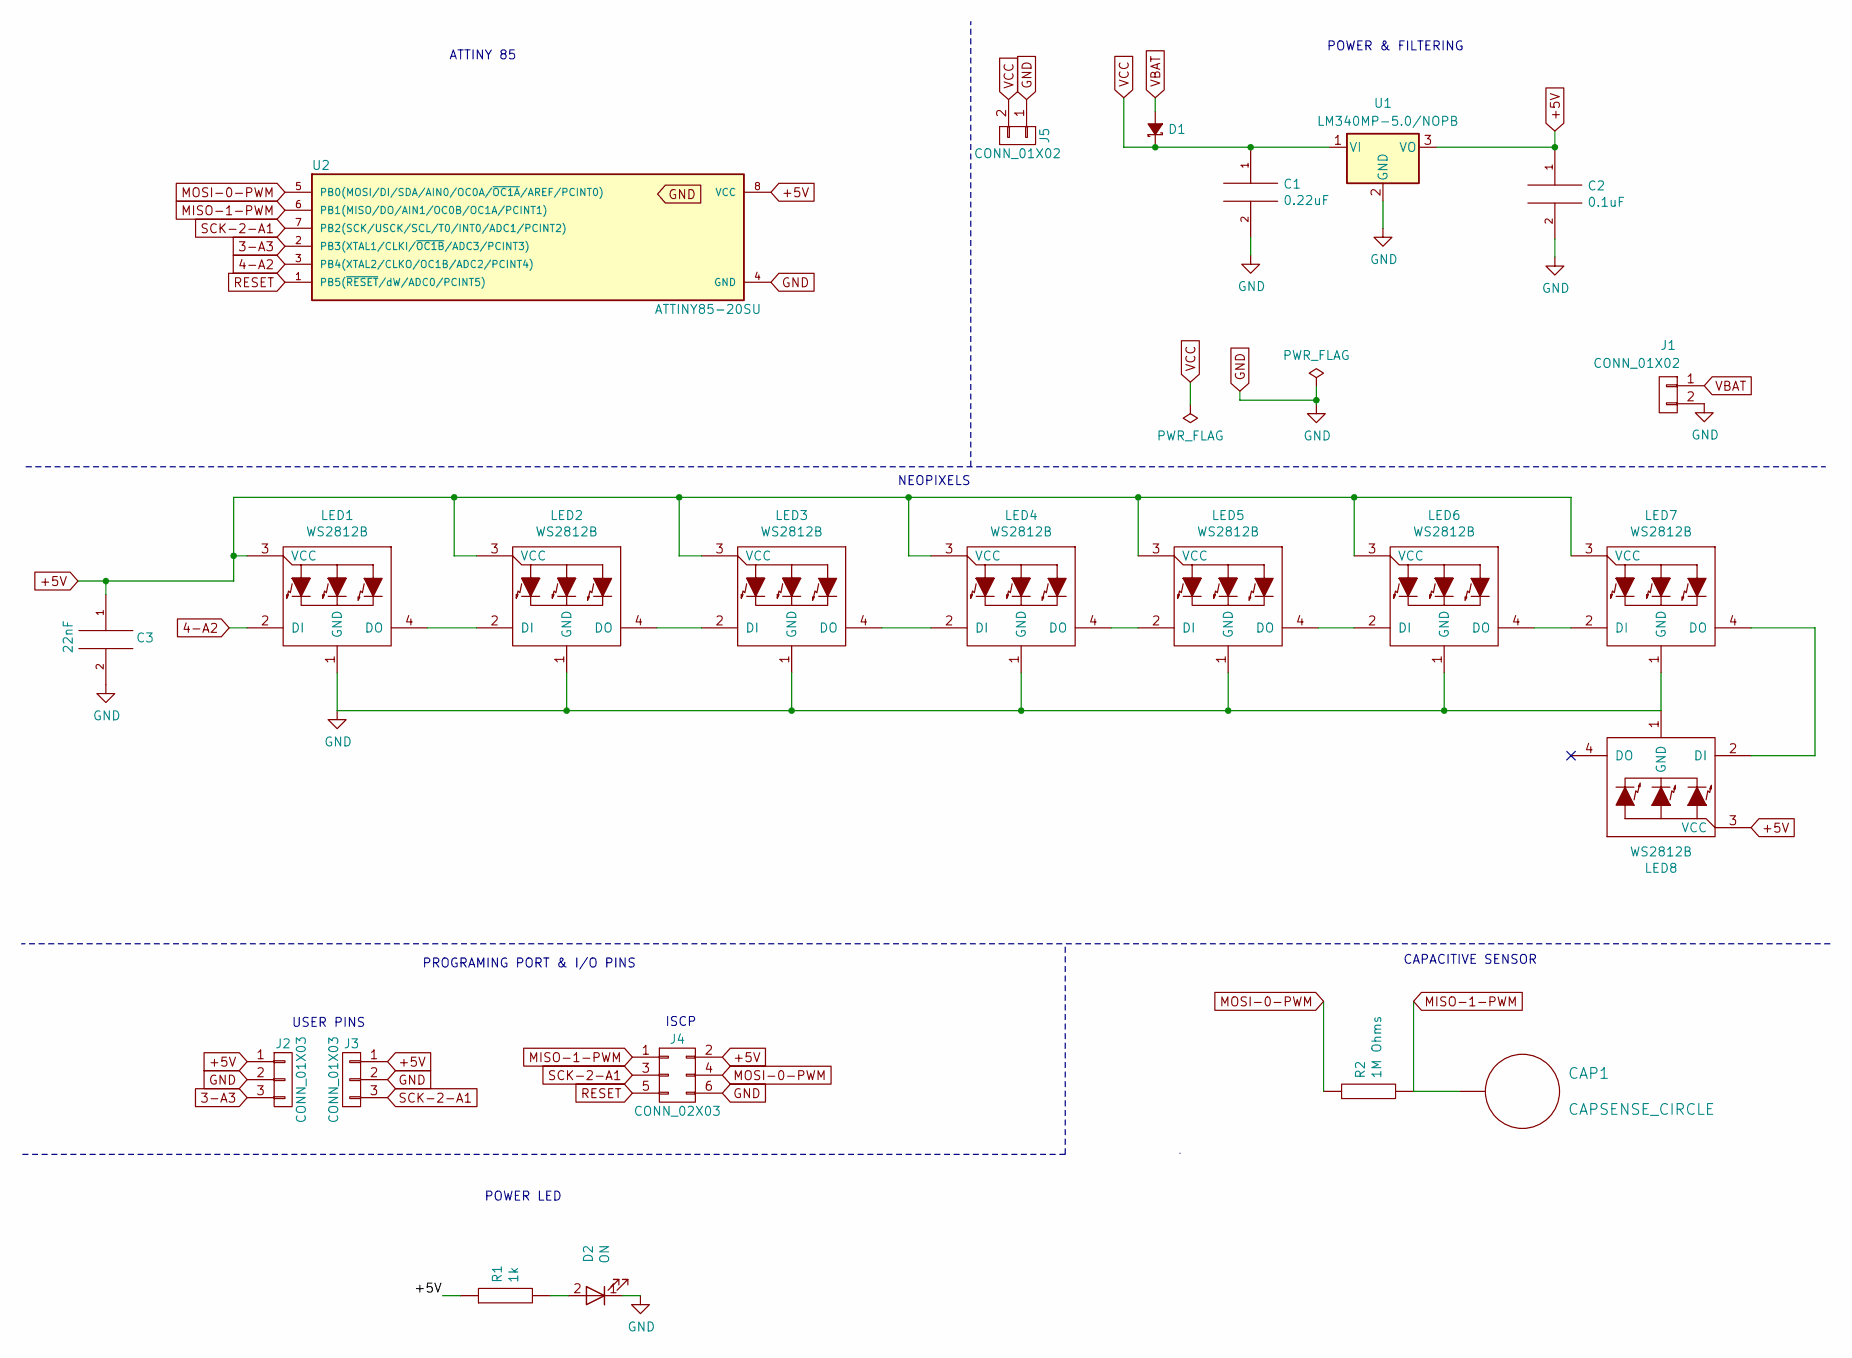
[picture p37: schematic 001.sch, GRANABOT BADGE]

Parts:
C1: 0.22uF; C_1206_HandSoldering
C2: 0.1uF; C_1206_HandSoldering
C3: 22nF; C_1206_HandSoldering
CAP1: CAPSENSE_CIRCLE; CAPSENSE-CIRCLE2-D10MM
D1: MBRA140; D_SOD-123
D2: ON; LED_1206_HandSoldering
J1: CONN_01X02; Molex_PicoBlade_53261-0271_02x1.25mm_Angled
J2: CONN_01X03; Pin_Header_Straight_1x03_Pitch2.54mm_SMD_Pin1Left
J3: CONN_01X03; Pin_Header_Straight_1x03_Pitch2.54mm_SMD_Pin1Right
J4: CONN_02X03; Pin_Header_Straight_2x03_Pitch2.54mm_SMD
J5: CONN_01X02; Pin_Header_Straight_1x02_Pitch2.54mm_SMD_Pin1Left
LED1, LED2, LED3, LED4, LED5, LED6, LED7, LED8: WS2812B
R1: 1k; R_1206_HandSoldering
R2: 1M Ohms; R_1206_HandSoldering
U1: LM340MP-5.0/NOPB; SOT-223-3Lead_TabPin2
U2: ATTINY85-20SU; SOIC-8_3.9x4.9mm_Pitch1.27mm

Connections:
3-A3: J2.3, U2.2 (PB3(XTAL1/CLKI/~OC1B~/ADC3/PCINT3))
4-A2: LED1.2 (DI), U2.3 (PB4(XTAL2/CLKO/OC1B/ADC2/PCINT4))
+5V: C2.1, C3.1, J2.1, J3.1, J4.2, LED1.3 (VCC), LED2.3 (VCC), LED3.3 (VCC), LED4.3 (VCC), LED5.3 (VCC), LED6.3 (VCC), LED7.3 (VCC), LED8.3 (VCC), R1.1, U1.3 (VO), U2.8 (VCC)
GND: C1.2, C2.2, C3.2, D2.1 (K), J1.2, J2.2, J3.2, J4.6, J5.1, LED1.1 (GND), LED2.1 (GND), LED3.1 (GND), LED4.1 (GND), LED5.1 (GND), LED6.1 (GND), LED7.1 (GND), LED8.1 (GND), U1.2 (GND), U2.4 (GND)
MISO-1-PWM: CAP1.1, J4.1, R2.2, U2.6 (PB1(MISO/DO/AIN1/OC0B/OC1A/PCINT1))
MOSI-0-PWM: J4.4, R2.1, U2.5 (PB0(MOSI/DI/SDA/AIN0/OC0A/~OC1A~/AREF/P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)
unnamed: D2.2 (A), R1.2
unnamed: LED1.4 (DO), LED2.2 (DI)
unnamed: LED2.4 (DO), LED3.2 (DI)
unnamed: LED3.4 (DO), LED4.2 (DI)
unnamed: LED4.4 (DO), LED5.2 (DI)
unnamed: LED5.4 (DO), LED6.2 (DI)
unnamed: LED6.4 (DO), LED7.2 (DI)
unnamed: LED7.4 (DO), LED8.2 (DI)
RESET: J4.5, U2.1 (PB5(~RESET~/dW/ADC0/PCINT5))
SCK-2-A1: J3.3, J4.3, U2.7 (PB2(SCK/USCK/SCL/T0/INT0/ADC1/PCINT2))
VBAT: D1.2 (A), J1.1
VCC: C1.1, D1.1 (K), J5.2, U1.1 (VI)

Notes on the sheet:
POWER & FILTERING
ATTINY 85
NEOPIXELS
PROGRAMING PORT & I/O PINS
CAPACITIVE SENSOR
ISCP
USER PINS
POWER LED

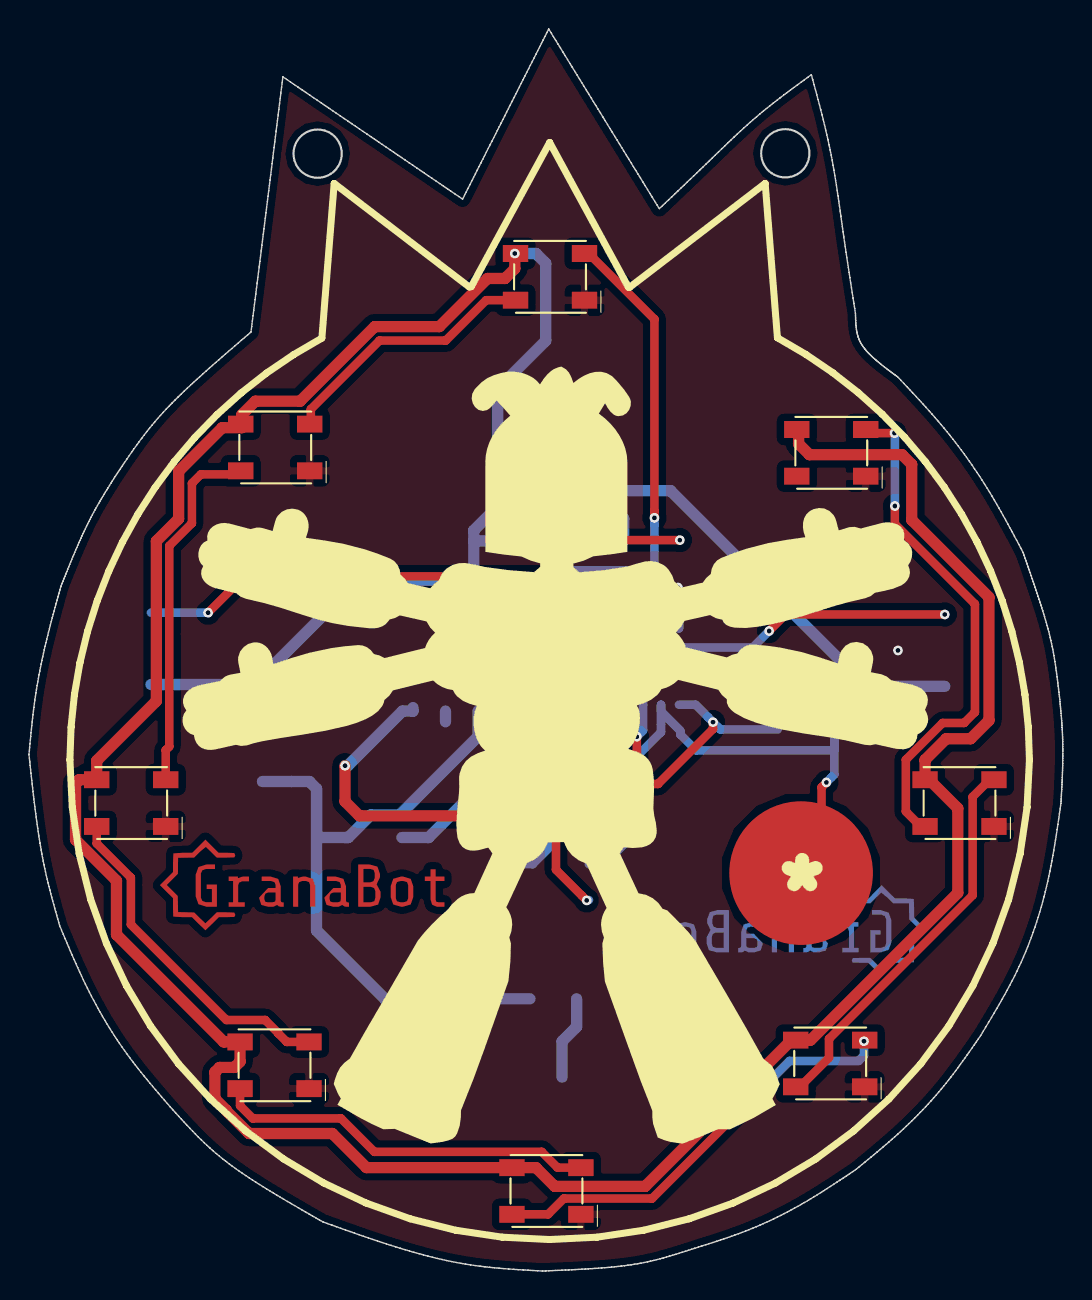
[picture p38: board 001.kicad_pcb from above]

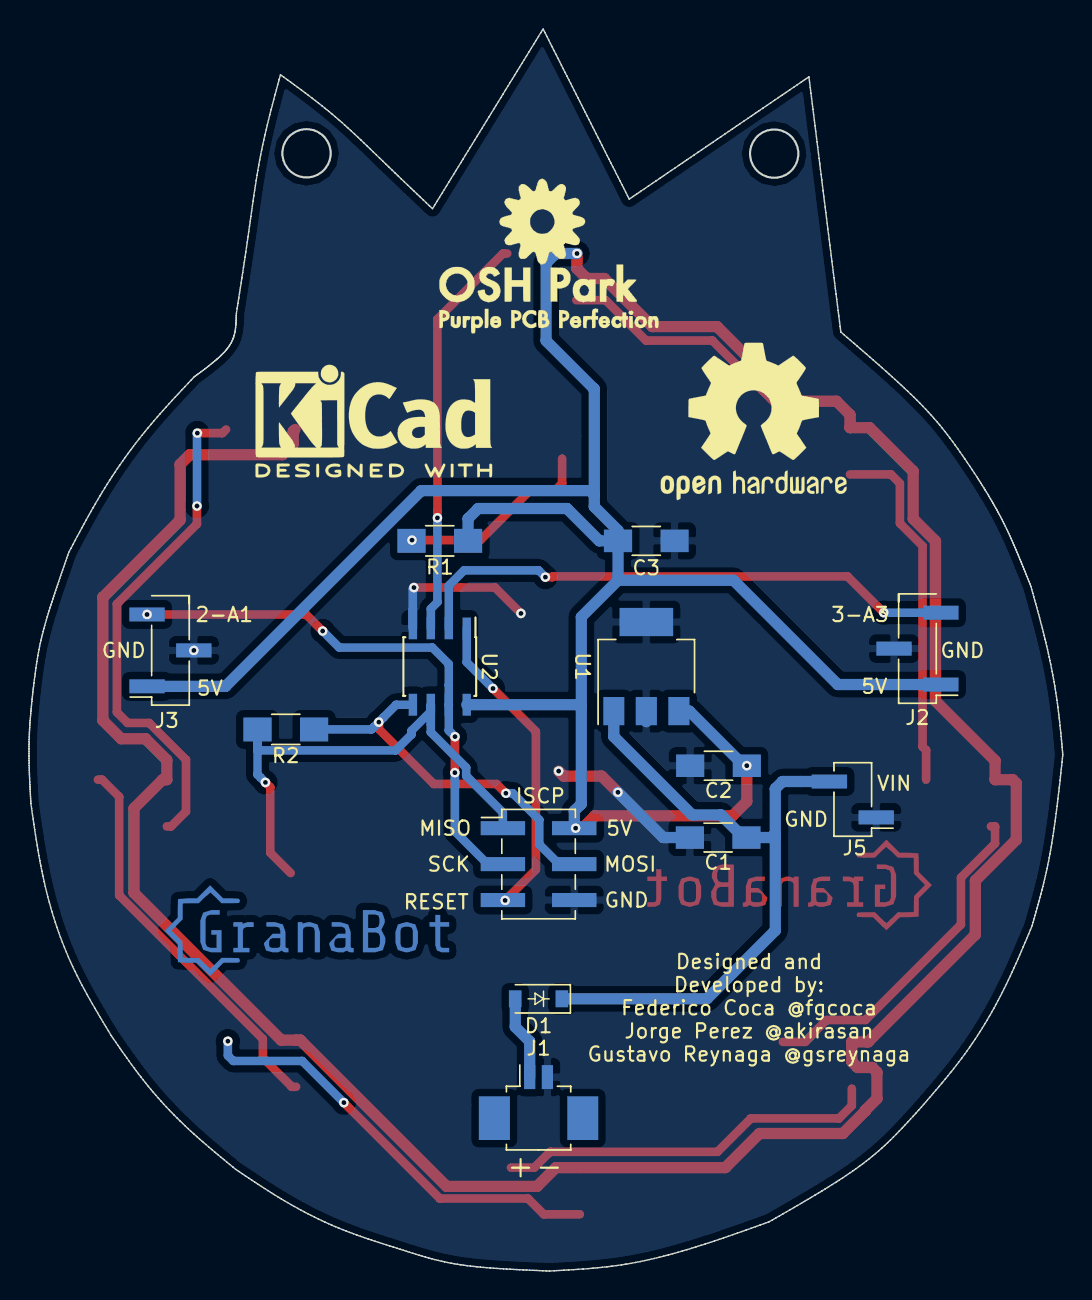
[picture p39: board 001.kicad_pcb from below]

Board: 2 copper layers, 73.1 x 87.8 mm, 28 parts (15 on the bottom side), 18 nets.

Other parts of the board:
svg2mod1: G***1; logo_letra_Cu
svg2mod2: G***2; logo_letra_Mask
svg2mod3: G***3; logo_letra_Cu
svg2mod4: G***4; logo_letra_Mask
svg2mod4#2: G***4; hormiga con borde

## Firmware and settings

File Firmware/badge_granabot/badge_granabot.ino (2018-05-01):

/************************************************************************************
 *    Programa test del badge de GranaBot                                           *
 *   -------------------------------------                                          *
 *                                                                                  *
 *    GranaBot 2018                                                                 *
 *                                                                                  *
 *    Paco López, Dpto. de Electrónica del I.E.S. Virgen de las Nieves, Granada.    *
 *                                                                                  *
 ************************************************************************************/

//El ATtiny85 deberá ser programado para que funcione a 8MHz o a 16MHz usando el reloj interno.

#include <Adafruit_NeoPixel.h>  //Para el control de los LEDs RGB.
#include <CapacitiveSensor.h>   //Para la lectura del sensor capacitivo incluido en la PCB del badge.

#define umbral 300        //Umbral para determinar si se está tocando el sensor. A mayor valor menor sensibilidad..
#define pin_leds PB4      //Los LEDs se controlan con el pin PB4 del ATtiny.
#define brillo 50         //Controla el brillo máximo de los LEDs.
#define antirrebotes 200  //Tiempo establecido entre lecturas sucesivas del sensor capacitivo, en ms.
#define retardo_ruleta 40 //Tiempo de reatrdo usado para controlar la velocidad de la "ruleta" de LEDs, en ms.

//Instanciación de los objetos usados en el sketch.
Adafruit_NeoPixel tira_leds = Adafruit_NeoPixel(8, pin_leds, NEO_GRB + NEO_KHZ800); //El badge tiene 8 LEDs RGB.
CapacitiveSensor cs_0_1 = CapacitiveSensor(PB0,PB1); //La resistencia de 1M está entre los pines PB0 y PB1. El pin PB1 es el que tiene conectado el sensor.

byte contador_de_toques=0;    //Para llevar la cuenta de las veces que se toca el sensor. Un máximo de 5 toques, tras los cuales la variable vuelve a valer 0.
                              //El valor de esta variable, el contador de toques, es el que determina el comportamiento del badge en cada instante.

void setup()                    
{
   tira_leds.setBrightness(brillo);     //Ajuste del brillo máximo.
   tira_leds.begin();                   //Inicialización del objeto "tira_leds".
   tira_leds.show();                    //Inicialmente todos los LEDs apagados (por defecto se tiene tira_leds.Color(0,0,0)).
}

void loop()                    
{
  //Lectura del sensor y control del contador de toques.
  long total_PB1 =  cs_0_1.capacitiveSensor(30);  //Lectura del sensor capacitivo. El valor leído se almacena en total_PB1.

  if (total_PB1 > umbral) //Si se ha tocado el sensor...
  {
    contador_de_toques++; //... se incrementa el contador de toques y ...
    if (contador_de_toques > 4) contador_de_toques = 0; //... se comprueba que su valor no exceda el máximo. Si es así se reinicia su valor a 0.
  }

  //Determinación del comportamiento del badge.
  switch (contador_de_toques)
    {
      case 0: //Todos los LEDs apagados.
              for(int cont=0; cont<9; cont++)
              {
                tira_leds.setPixelColor(cont, tira_leds.Color(0,0,0));  //Se configuran todos los LEDs para que se apaguen...
              }
              tira_leds.show();                                         //... y se manda esta configuración al badge (actualización del estado de los LEDs).
              delay(antirrebotes);                                      //Para evitar nuevas lecturas del sensor antes de que dé tiempo de retirar el dedo.
              break;
              
      case 1: //Todos los LEDs a rojo.
              for(int cont=0; cont<9; cont++)
              {
                tira_leds.setPixelColor(cont, tira_leds.Color(255,0,0));
              }
              tira_leds.show();
              delay(antirrebotes);
              break;
              
      case 2: //Todos los LEDs a verde.
              for(int cont=0; cont<9; cont++)
              {
                tira_leds.setPixelColor(cont, tira_leds.Color(0,255,0));
              }
              tira_leds.show();
              delay(antirrebotes);
              break;
              
      case 3: //Todos los LEDs a azul
              for(int cont=0; cont<9; cont++)
              {
                tira_leds.setPixelColor(cont, tira_leds.Color(0,0,255));
              }
              tira_leds.show();
              delay(antirrebotes);
              break;
              
      case 4: //FX (efectos especiales) de LEDs bailoteando.
              delay(antirrebotes);    //Para evitar nuevas lecturas del sensor antes de que dé tiempo de retirar el dedo.
              bailoteo_leds();        //Llamada a la función de bailoteo de los LEDs.
              break;
    }
}




//-------------------------------------------------------------//
//                DEFINICIÓN DE FUNCIONES PROPIAS              //
//-------------------------------------------------------------//

//Función que realiza un FX.
//Esta función está diseñada en principio para llamar a la función vuelta_ruleta(), pero es
//fácilmente modificable para usar otras funciones de efectos diferentes (a diseñar por el futuro
//programador del badge).
void bailoteo_leds (void)
{
  while(1)  //La ruleta de LEDs se ejecutará de forma indefinida...
  {
    if( vuelta_ruleta(255,0,0) )     return;  //... hasta que alguna de las llamadas a la función vuelta_ruleta() devuelva el valor true.
    if( vuelta_ruleta(255,255,0) )   return;
    if( vuelta_ruleta(0,255,0) )     return;
    if( vuelta_ruleta(0,255,255) )   return;
    if( vuelta_ruleta(0,0,255) )     return;
    if( vuelta_ruleta(255,0,255) )   return;
    if( vuelta_ruleta(255,255,255) ) return;
  }
}

//Cada llamada a esta función realiza una vuelta completa de la ruleta de LEDs. En concreto, se realiza un
//encendido sucesivo de los LEDs del badge, simulando el efecto de una ruleta de LEDs con colores cambiantes.
//La función requiere como parámetros el color, en formato RGB, con el que deben ir encendiéndose los LEDs.
//La función retorna un valor lógico dependiendo de que durante su ejecución se active o no el sensor capacitivo:
//      true  -> se ha producido la activación del sensor durante la ejecución de la función.
//      false -> no se ha producido la activación del sensor.
boolean vuelta_ruleta (byte r, byte g, byte b)
{
  for(int cont=0; cont<9; cont++)   //Para ir encendiendo progresivamente cada uno de los 8 LEDs del badge.
      {
        tira_leds.setPixelColor(cont, tira_leds.Color(r,g,b));  //Se configura el LED indicado por cont con el color dado como parámetro de la función.
        tira_leds.show();                                       //Se actualiza el estado del LED.
        if (cs_0_1.capacitiveSensor(30) > umbral)               //Cada vez que se procede a actualizar un LED se realiza la lectura del sensor...
        {                                                       //... y si se ha activado entonces...
          contador_de_toques = 0;                               //... se restituye el contador de toques a su valor inicial, ...
          delay(antirrebotes);                                  //... se espera el tiempo antirrebote para dejar tiempo de retirar el dedo del sensor y ...
          return true;                                          //... se retorna devolviendo el valor true.
        }
        delay(retardo_ruleta);                                  //En caso de no haberse activado el sensor se introduce un retardo para que el encendido ...
      }                                                         //... de los LEDs de la ruleta no sea demasiado rápido, ya que entonces se perdería el efecto buscado ...
      return false;                                             //... y se retorna devolviendo el valor false.
}
